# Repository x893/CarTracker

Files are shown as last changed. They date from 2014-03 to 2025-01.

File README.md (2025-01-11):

CarTracker
==========

CarTracker
STM32F10xCx, STM32F10xRx, STM32F205Rx, STM32F405Rx, STM32L1xxCx, STM32L1xxRx support.
Telit SL868 or SL869
Telit GL865 or GL868
CAN support,
MMA7455 accelerometer,
standard SIM or SIM On Chip
64 pins version can use battery, USB and RFM70 module (or other)

Shared PCB on OSH Park:

Cx version http://oshpark.com/shared_projects/hou07XOD

Rx version http://oshpark.com/shared_projects/wFTza6Pe

Cx version support direct connection GPS to GSM via wires (or change layout) so you can use buildin Python to implement tracker functions without STM32 MCU.

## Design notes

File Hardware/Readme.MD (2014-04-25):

Eagle Cadsoft
Case http://www.gainta.com/en/g431.html
See info for R9 value and R13

Shared PCB on OSH Park:

Cx version http://oshpark.com/shared_projects/hou07XOD
Rx version http://oshpark.com/shared_projects/wFTza6Pe

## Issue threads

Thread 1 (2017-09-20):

Online Diagnostic and GPS

aytekno, 2017-09-20:
Hello,
We want to use your product for online diagnostic and tracking. We do not want the processes online, just want to record the data on a SD card . We opened the pcb files and we could not see micro sd card slot. In your previous design there was. What do you prefer? Have you ever try this card for CanBus?
Thank you in advance.

x893, 2017-09-20:
Hello, SD card not need for my application. But you can add SD card to board or redesign for your box. My board (both variants) contains CAN adapter but also you can add modern CAN bus variants. So you can change as you need. You can contact with me via skype - see in top left corner on my site.

toxatt, 2019-05-10:
Hello. Have you realization collecting data to flash memory when have no GSM signal?

x893, 2019-05-24:
Yes, many years ago. As ring buffer but for microtracker (MX25 flash chip). See on site my site for device. Algorithm very simple - nothing interesting.

Closed 2025-01-11.

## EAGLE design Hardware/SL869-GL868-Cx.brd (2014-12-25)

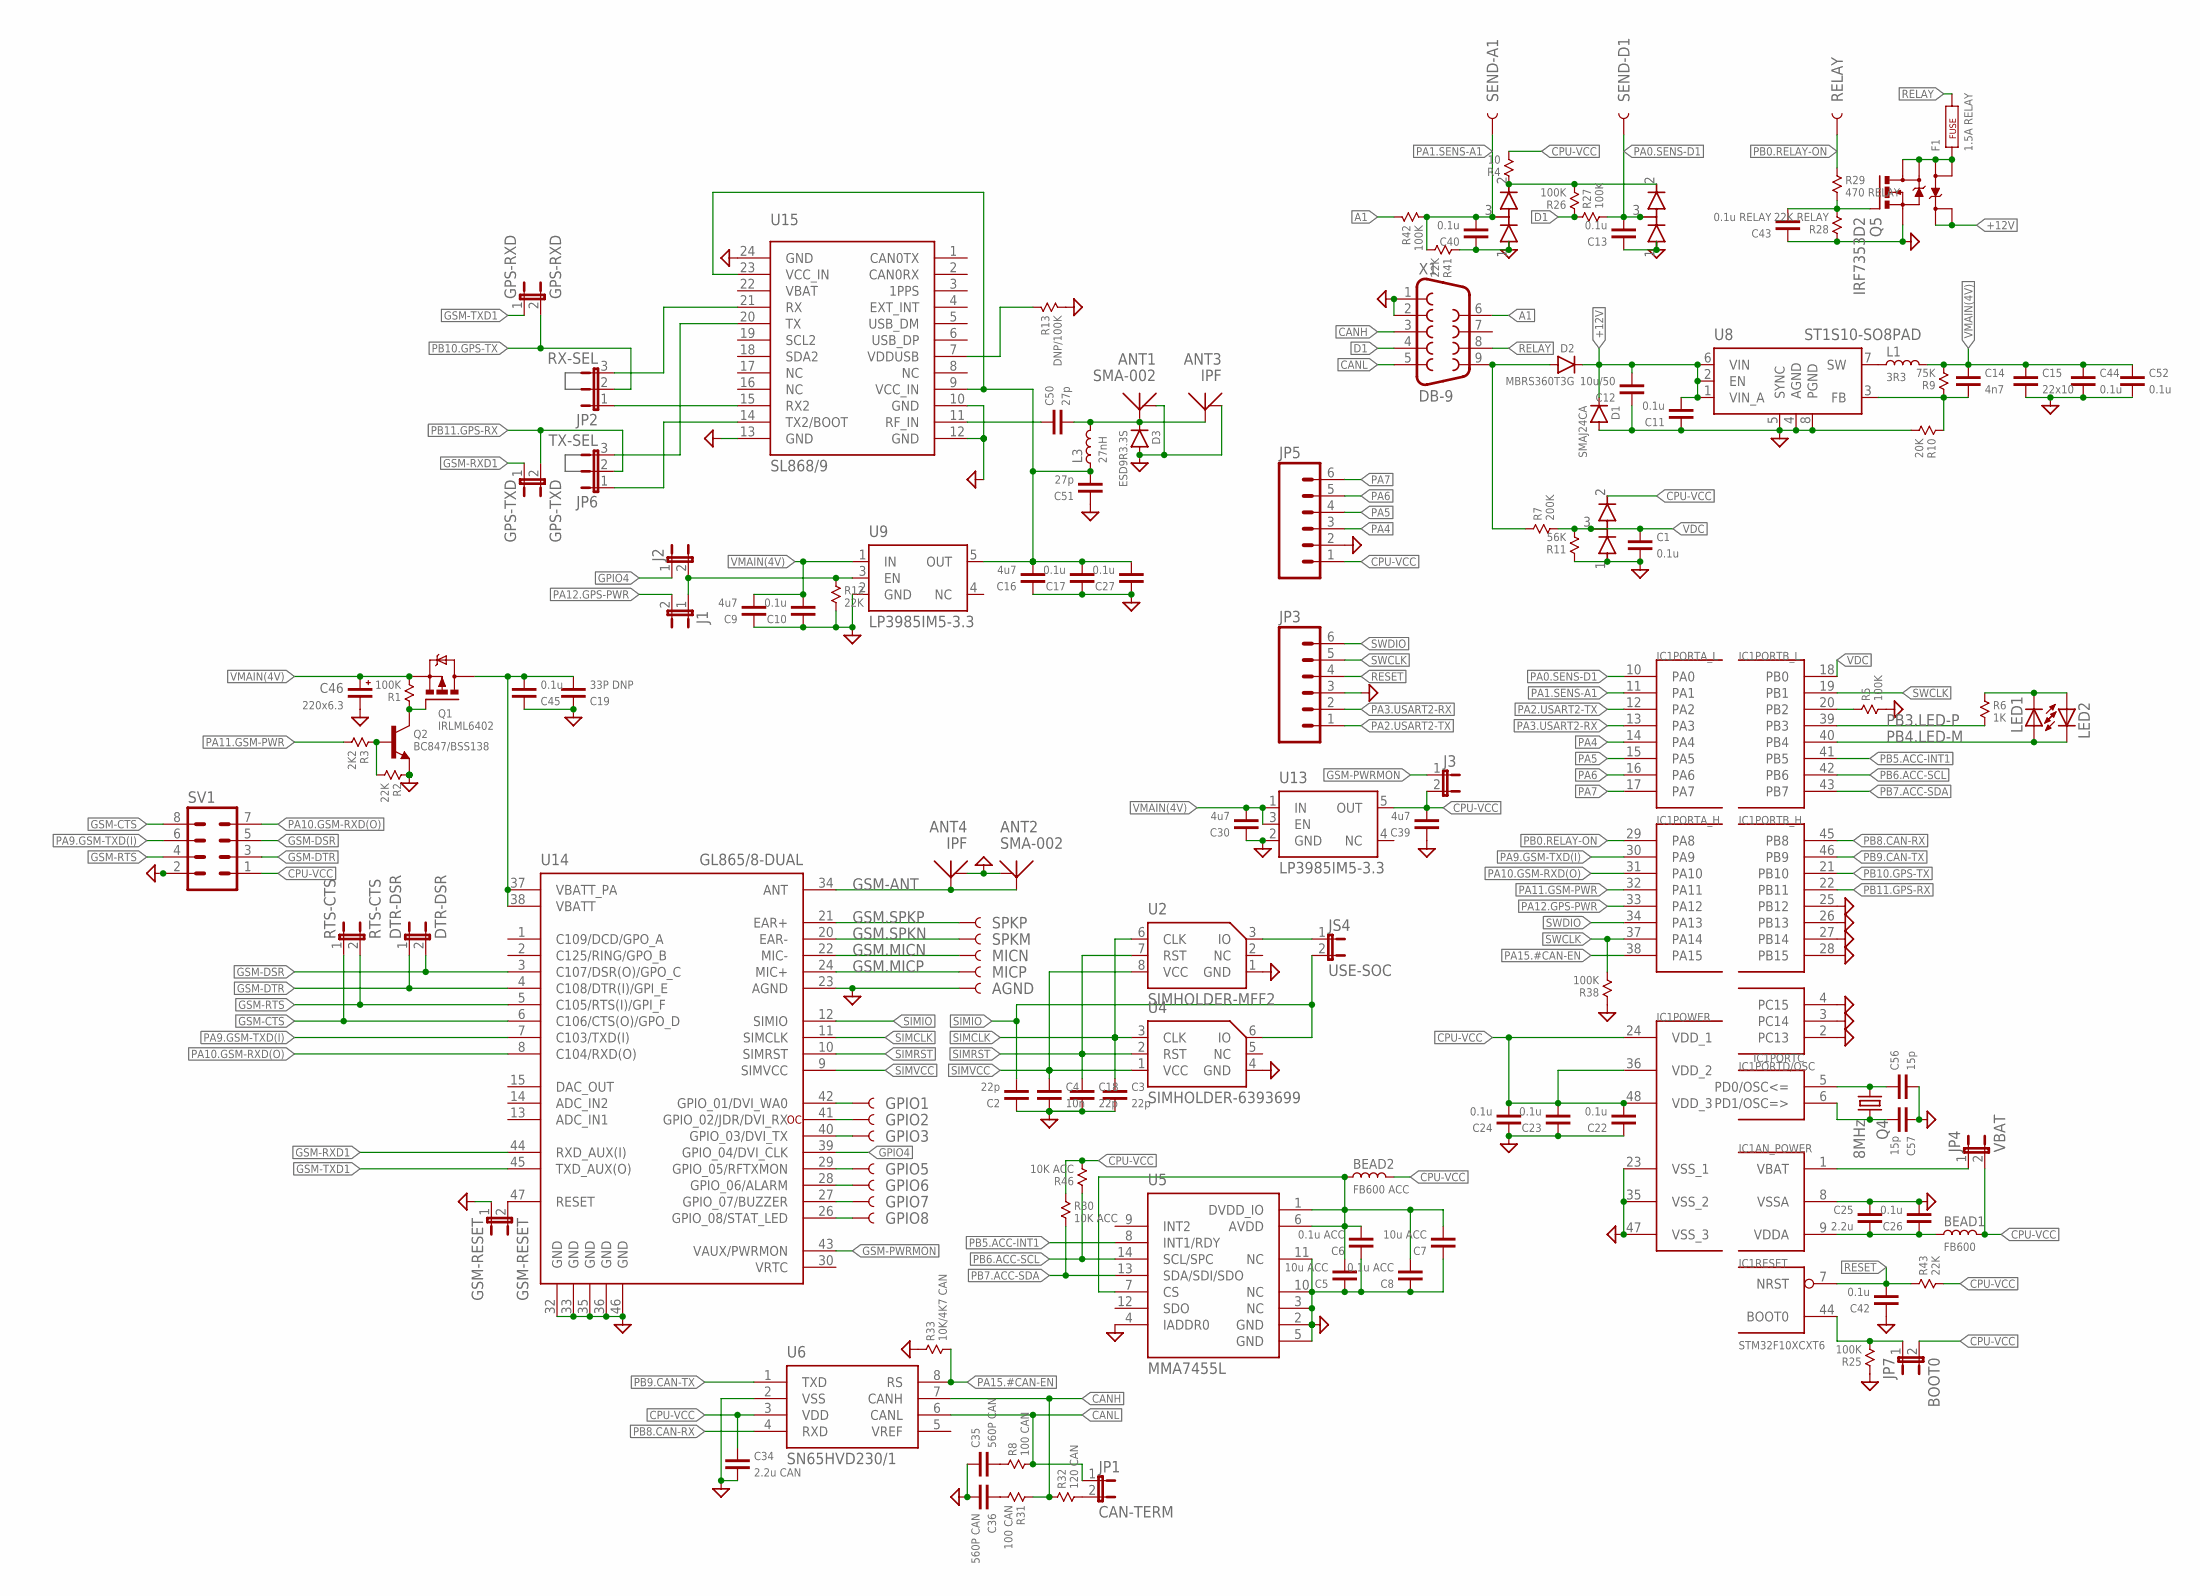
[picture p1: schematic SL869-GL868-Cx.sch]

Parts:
AGND: TEST-POINT1; PAD.1X1
ANT1, ANT2: SMA-002
ANT3, ANT4: IPF; MM9329
BEAD1: FB600; 0603
BEAD2: FB600 ACC; 0603
C1, C10, C11, C13, C17, C22, C23, C24, C26, C27, C40, C42, C44, C45, C52: 0.1u; 0603
C2, C3, C18: 22p; 0603
C4: 10n; 0603
C5, C7: 10u ACC; 0603
C6, C8: 0.1u ACC; 0603
C9, C16, C30, C39: 4u7; 0603
C12: 10u/50; 1206
C14: 4n7; 0603
C15: 22x10; 1206
C19: 33P DNP; 0603
C25: 2.2u; 0603
C34: 2.2u CAN; 0603
C35, C36: 560P CAN; 0603
C43: 0.1u RELAY; 0603
C46: 220x6.3; CT7343
C50, C51: 27p; 0603
C56, C57: 15p; 0603
D1: SMAJ24CA; SMA
D2: MBRS360T3G; SMC
D3: ESD9R3.3S; SOD-923
D4, D5, D14: BAV99; SOT-23
DTR-DSR: DTR-DSR; SJ_2S-NO
F1: 1.5A RELAY; 1812
GPIO1, GPIO2, GPIO3, GPIO5, GPIO6, GPIO7, GPIO8: TEST-POINT1; PAD.1X1
GPS-RXD: GPS-RXD; SJ_2S-NO
GPS-TXD: GPS-TXD; SJ_2S-NO
GSM-RESET: GSM-RESET; SJ_2S-NO
IC1: STM32F10XCXT6; TQFP48
J1, J2, J3: JUMPER-2SMD-NO; SJ_2S-NO
JP1: CAN-TERM; SJ_2S-NO
JP2: RX-SEL; SJ_3
JP3, JP5: M06SIP; 1X06
JP4: VBAT; SJ_2S-NO
JP6: TX-SEL; SJ_3
JP7: BOOT0; SJ_2S-NO
JS4: USE-SOC; SJ_2S-NO
L1: 3R3; CDRH6D38NP
L3: 27nH; 0603
LED1, LED2: LED3MM
MICN: TEST-POINT1; PAD.1X1
MICP: TEST-POINT1; PAD.1X1
Q1: IRLML6402; SOT-23
Q2: BC847/BSS138; SOT-23
Q4: 8MHz; HC49U-V
Q5: IRF7353D2; SO08
R1, R5, R25, R26, R27, R38, R42: 100K; 0603
R2, R12, R41, R43: 22K; 0603
R3: 2K2; 0603
R4: 10; 0603
R6: 1K; 0603
R7: 200K; 0603
R8, R31: 100 CAN; 0603
R9: 75K; 0603
R10: 20K; 0603
R11: 56K; 0603
R13: DNP/100K; 0603
R28: 22K RELAY; 0603
R29: 470 RELAY; 0603
R30, R46: 10K ACC; 0603
R32: 120 CAN; 0603
R33: 10K/4K7 CAN; 0603
RELAY: TEST-POINT1; PAD.1X1
RTS-CTS: RTS-CTS; SJ_2S-NO
SEND-A1: TEST-POINT1; PAD.1X1
SEND-D1: TEST-POINT1; PAD.1X1
SPKM: TEST-POINT1; PAD.1X1
SPKP: TEST-POINT1; PAD.1X1
SV1: MA04-2
U2: SIMHOLDER-MFF2; MFF2
U4: SIMHOLDER-6393699; 6393699-1
U5: MMA7455L; LGA14
U6: SN65HVD230/1; SO08
U8: ST1S10-SO8PAD; SO08-EPAD
U9, U13: LP3985IM5-3.3; SOT23-5
U14: GL865/8-DUAL
U15: SL868/9
X1: DB-9; DB9

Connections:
+12-IN: D2.P$2 (A), R7.1, X1.9
+12V: C11.1, C12.1, D1.P$1 (C), D2.P$1 (C), Q5.7 (K), Q5.8 (K), U8.1 (VIN_A), U8.2 (EN), U8.6 (VIN)
A1: R42.1, X1.6
ACC-VCC: BEAD2.1, C5.1, C6.1, C7.1, C8.1, U5.1 (DVDD_IO), U5.6 (AVDD), U5.7 (CS)
CANH: R31.1, R32.1, U6.7 (CANH), X1.3
CANL: JP1.1, R8.2, U6.6 (CANL), X1.5
CPU-VBAT: IC1.1 (VBAT), JP4.1
CPU-VCC: BEAD1.2, BEAD2.2, C22.1, C23.1, C24.1, C34.2, C39.1, D5.2 (+), IC1.24 (VDD_1), IC1.36 (VDD_2), IC1.48 (VDD_3), J3.2, JP4.2, JP5.1, JP7.2, R4.2, R30.1, R43.2, R46.2, SV1.1, U6.3 (VDD), U13.5 (OUT)
D1: R26.1, R27.1, X1.4
GND: AGND.P$1, ANT1.GND@1 (GND), ANT2.GND@1 (GND), ANT3.2 (GND), ANT4.2 (GND), C1.1, C2.2, C3.1, C4.1, C5.2, C6.2, C7.2, C8.2, C9.2, C10.2, C11.2, C12.2, C13.2, C15.1, C16.2, C17.2, C18.1, C19.2, C22.2, C23.2, C24.2, C25.2, C26.1, C27.2, C30.2, C34.1, C35.2, C36.1, C39.2, C40.2, C42.2, C43.2, C44.1, C45.2, C46.-, C51.2, C52.1, C56.1, C57.2, D1.P$2 (A), D3.2 (A), D4.1 (-), D5.1 (-), D14.1 (-), GSM-RESET.1, IC1.2 (PC13), IC1.3 (PC14), IC1.4 (PC15), IC1.8 (VSSA), IC1.23 (VSS_1), IC1.25 (PB12), IC1.26 (PB13), IC1.27 (PB14), IC1.28 (PB15), IC1.35 (VSS_2), IC1.47 (VSS_3), JP3.3, JP5.2, Q2.2 (E), Q5.3 (S), R2.1, R5.2, R10.2, R11.1, R12.2, R13.2, R25.1, R28.1, R33.1, R38.1, R41.1, SV1.2, U2.1 (GND), U4.4 (GND), U5.2 (GND), U5.3 (NC), U5.4 (IADDR0), U5.5 (GND), U5.10 (NC), U5.11 (NC), U6.2 (VSS), U8.4 (AGND), U8.5 (SYNC), U8.8 (PGND), U9.2 (GND), U13.2 (GND), U14.23 (AGND), U14.32 (GND), U14.33 (GND), U14.35 (GND), U14.36 (GND), U14.46 (GND), U15.10 (GND), U15.12 (GND), U15.13 (GND), U15.24 (GND), X1.1, X1.2
GPIO1: GPIO1.P$1, U14.42 (GPIO_01/DVI_WA0)
GPIO2: GPIO2.P$1, U14.41 (GPIO_02/JDR/DVI_RX)
GPIO3: GPIO3.P$1, U14.40 (GPIO_03/DVI_TX)
GPIO4: J2.1, U14.39 (GPIO_04/DVI_CLK)
GPIO5: GPIO5.P$1, U14.29 (GPIO_05/RFTXMON)
GPIO6: GPIO6.P$1, U14.28 (GPIO_06/ALARM)
GPIO7: GPIO7.P$1, U14.27 (GPIO_07/BUZZER)
GPIO8: GPIO8.P$1, U14.26 (GPIO_08/STAT_LED)
GPS-PWR: J1.1, J2.2, R12.1, U9.3 (EN)
GPS-RX0: JP2.1, U15.15 (RX2)
GPS-RX1: JP2.3, U15.21 (RX)
GPS-TX0: JP6.1, U15.14 (TX2/BOOT)
GPS-TX1: JP6.3, U15.20 (TX)
GPS-VCC: C16.1, C17.1, C27.1, C51.1, L3.1, U9.5 (OUT), U15.9 (VCC_IN), U15.23 (VCC_IN)
GSM-ANT: ANT2.A (ANT), ANT4.1 (ANT), U14.34 (ANT)
GSM-CTS: RTS-CTS.1, SV1.8, U14.6 (C106/CTS(O)/GPO_D)
GSM-DSR: DTR-DSR.2, SV1.5, U14.3 (C107/DSR(O)/GPO_C)
GSM-DTR: DTR-DSR.1, SV1.3, U14.4 (C108/DTR(I)/GPI_E)
GSM-PWRMON: J3.1, U14.43 (VAUX/PWRMON)
GSM-RESET: GSM-RESET.2, U14.47 (RESET)
GSM-RTS: RTS-CTS.2, SV1.4, U14.5 (C105/RTS(I)/GPI_F)
GSM-RXD1: GPS-TXD.1, U14.44 (RXD_AUX(I))
GSM-TXD1: GPS-RXD.1, U14.45 (TXD_AUX(O))
GSM-VCC: C19.1, C45.1, Q1.3 (D), U14.37 (VBATT_PA), U14.38 (VBATT)
GSM.MICN: MICN.P$1, U14.22 (MIC-)
GSM.MICP: MICP.P$1, U14.24 (MIC+)
GSM.SPKN: SPKM.P$1, U14.20 (EAR-)
GSM.SPKP: SPKP.P$1, U14.21 (EAR+)
unnamed: JP1.2, R32.2
unnamed: IC1.20 (PB2), R5.1
unnamed: F1.1, Q5.1 (A), Q5.2 (A), Q5.5 (D), Q5.6 (D)
unnamed: Q1.1 (G), Q2.3 (C), R1.1
unnamed: JS4.1, U2.3 (IO)
unnamed: C50.2, U15.11 (RF_IN)
unnamed: Q2.1 (B), R2.2, R3.1
unnamed: L1.P$1 (1), U8.7 (SW)
unnamed: C35.1, R8.1
unnamed: C36.2, R31.2
unnamed: R13.1, U15.7 (VDDUSB)
unnamed: LED1.K (C), LED2.A, R6.1
unnamed: C56.2, IC1.5 (PD0/OSC<=), Q4.1
unnamed: IC1.44 (BOOT0), JP7.1, R25.2
unnamed: C14.1, R9.1, R10.1, U8.3 (FB)
unnamed: C57.1, IC1.6 (PD1/OSC=>), Q4.2
unnamed: ANT1.A (ANT), ANT3.1 (ANT), C50.1, D3.1 (C), L3.2
unnamed: C43.1, Q5.4 (G), R28.2, R29.2
PA0.SENS-D1: C13.1, D4.3 (S), IC1.10 (PA0), R27.2, SEND-D1.P$1
PA1.SENS-A1: C40.1, D14.3 (S), IC1.11 (PA1), R41.2, R42.2, SEND-A1.P$1
PA2.USART2-TX: IC1.12 (PA2), JP3.1
PA3.USART2-RX: IC1.13 (PA3), JP3.2
PA4: IC1.14 (PA4), JP5.3
PA5: IC1.15 (PA5), JP5.4
PA6: IC1.16 (PA6), JP5.5
PA7: IC1.17 (PA7), JP5.6
PA9.GSM-TXD(I): IC1.30 (PA9), SV1.6, U14.7 (C103/TXD(I))
PA10.GSM-RXD(O): IC1.31 (PA10), SV1.7, U14.8 (C104/RXD(O))
PA11.GSM-PWR: IC1.32 (PA11), R3.2
PA12.GPS-PWR: IC1.33 (PA12), J1.2
PA15.#CAN-EN: IC1.38 (PA15), R33.2, U6.8 (RS)
PB0.RELAY-ON: IC1.29 (PA8), R29.1, RELAY.P$1
PB3.LED-P: IC1.39 (PB3), R6.2
PB4.LED-M: IC1.40 (PB4), LED1.A, LED2.K (C)
PB5.ACC-INT1: IC1.41 (PB5), U5.8 (INT1/RDY)
PB6.ACC-SCL: IC1.42 (PB6), R46.1, U5.14 (SCL/SPC)
PB7.ACC-SDA: IC1.43 (PB7), R30.2, U5.13 (SDA/SDI/SDO)
PB8.CAN-RX: IC1.45 (PB8), U6.4 (RXD)
PB9.CAN-TX: IC1.46 (PB9), U6.1 (TXD)
PB10.GPS-TX: GPS-RXD.2, IC1.21 (PB10), JP2.2
PB11.GPS-RX: GPS-TXD.2, IC1.22 (PB11), JP6.2
RELAY: F1.2, X1.8
RESET: C42.1, IC1.7 (NRST), JP3.4, R43.1
SENS-VCC: D4.2 (+), D14.2 (+), R4.1, R26.2
SIMCLK: C3.2, U2.6 (CLK), U4.3 (CLK), U14.11 (SIMCLK)
SIMIO: C2.1, JS4.2, U4.6 (IO), U14.12 (SIMIO)
SIMRST: C18.2, U2.7 (RST), U4.2 (RST), U14.10 (SIMRST)
SIMVCC: C4.2, U2.8 (VCC), U4.1 (VCC), U14.9 (SIMVCC)
SWCLK: IC1.19 (PB1), IC1.37 (PA14), JP3.5, R38.2
SWDIO: IC1.34 (PA13), JP3.6
VDC: C1.2, D5.3 (S), IC1.18 (PB0), R7.2, R11.2
VDDA: BEAD1.1, C25.1, C26.2, IC1.9 (VDDA)
VMAIN(4V): C9.1, C10.1, C14.2, C15.2, C30.1, C44.2, C46.+, C52.2, L1.P$2 (2), Q1.2 (S), R1.2, R9.2, U9.1 (IN), U13.1 (IN), U13.3 (EN)

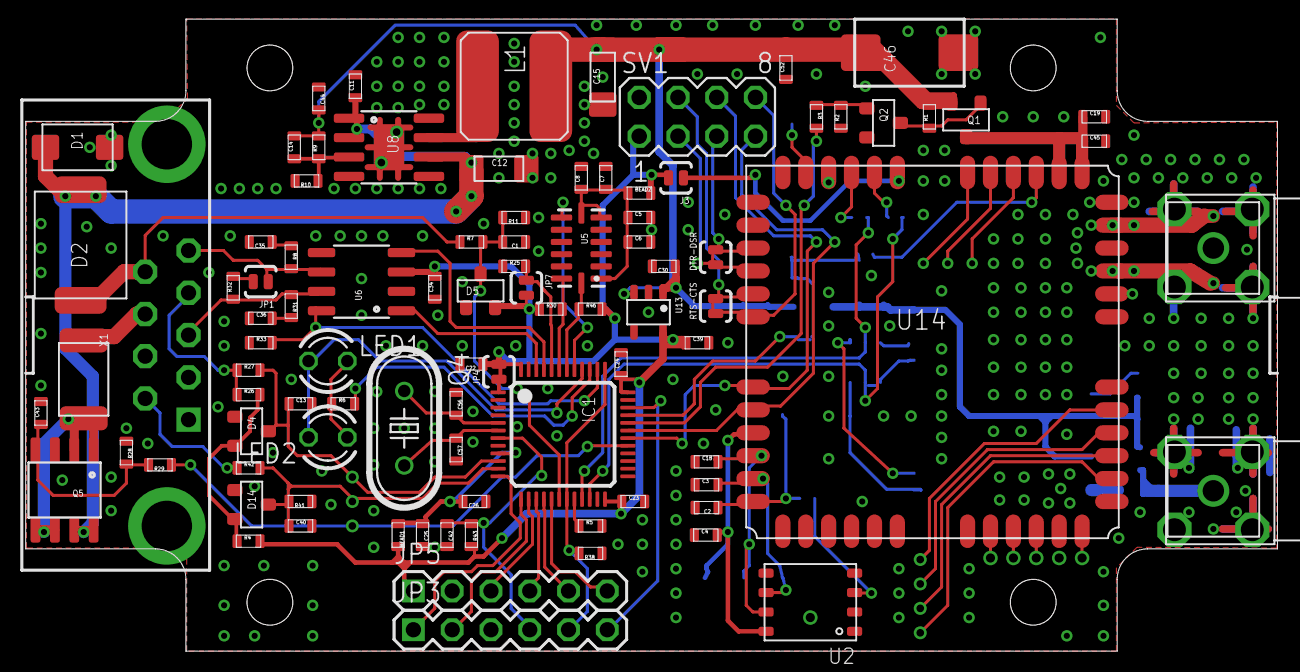
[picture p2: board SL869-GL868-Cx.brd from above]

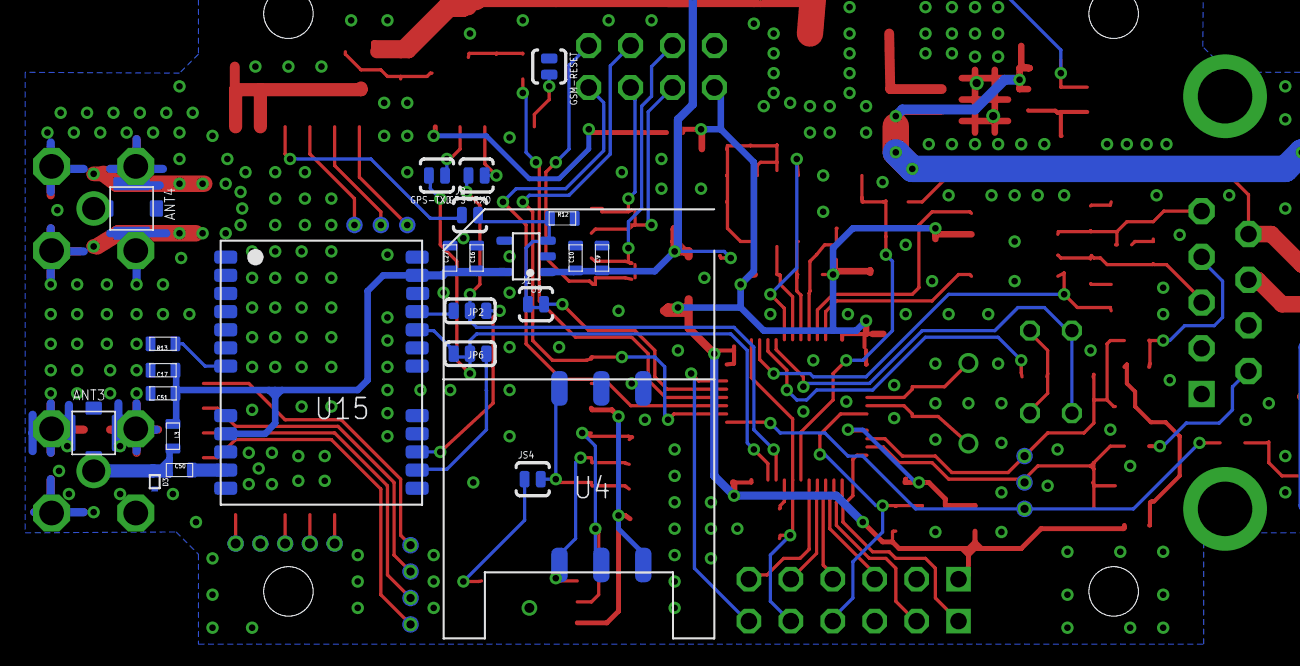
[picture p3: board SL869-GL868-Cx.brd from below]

Board: 2 copper layers, 133 parts (39 on the bottom side), 91 nets.

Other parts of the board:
U$1: G403

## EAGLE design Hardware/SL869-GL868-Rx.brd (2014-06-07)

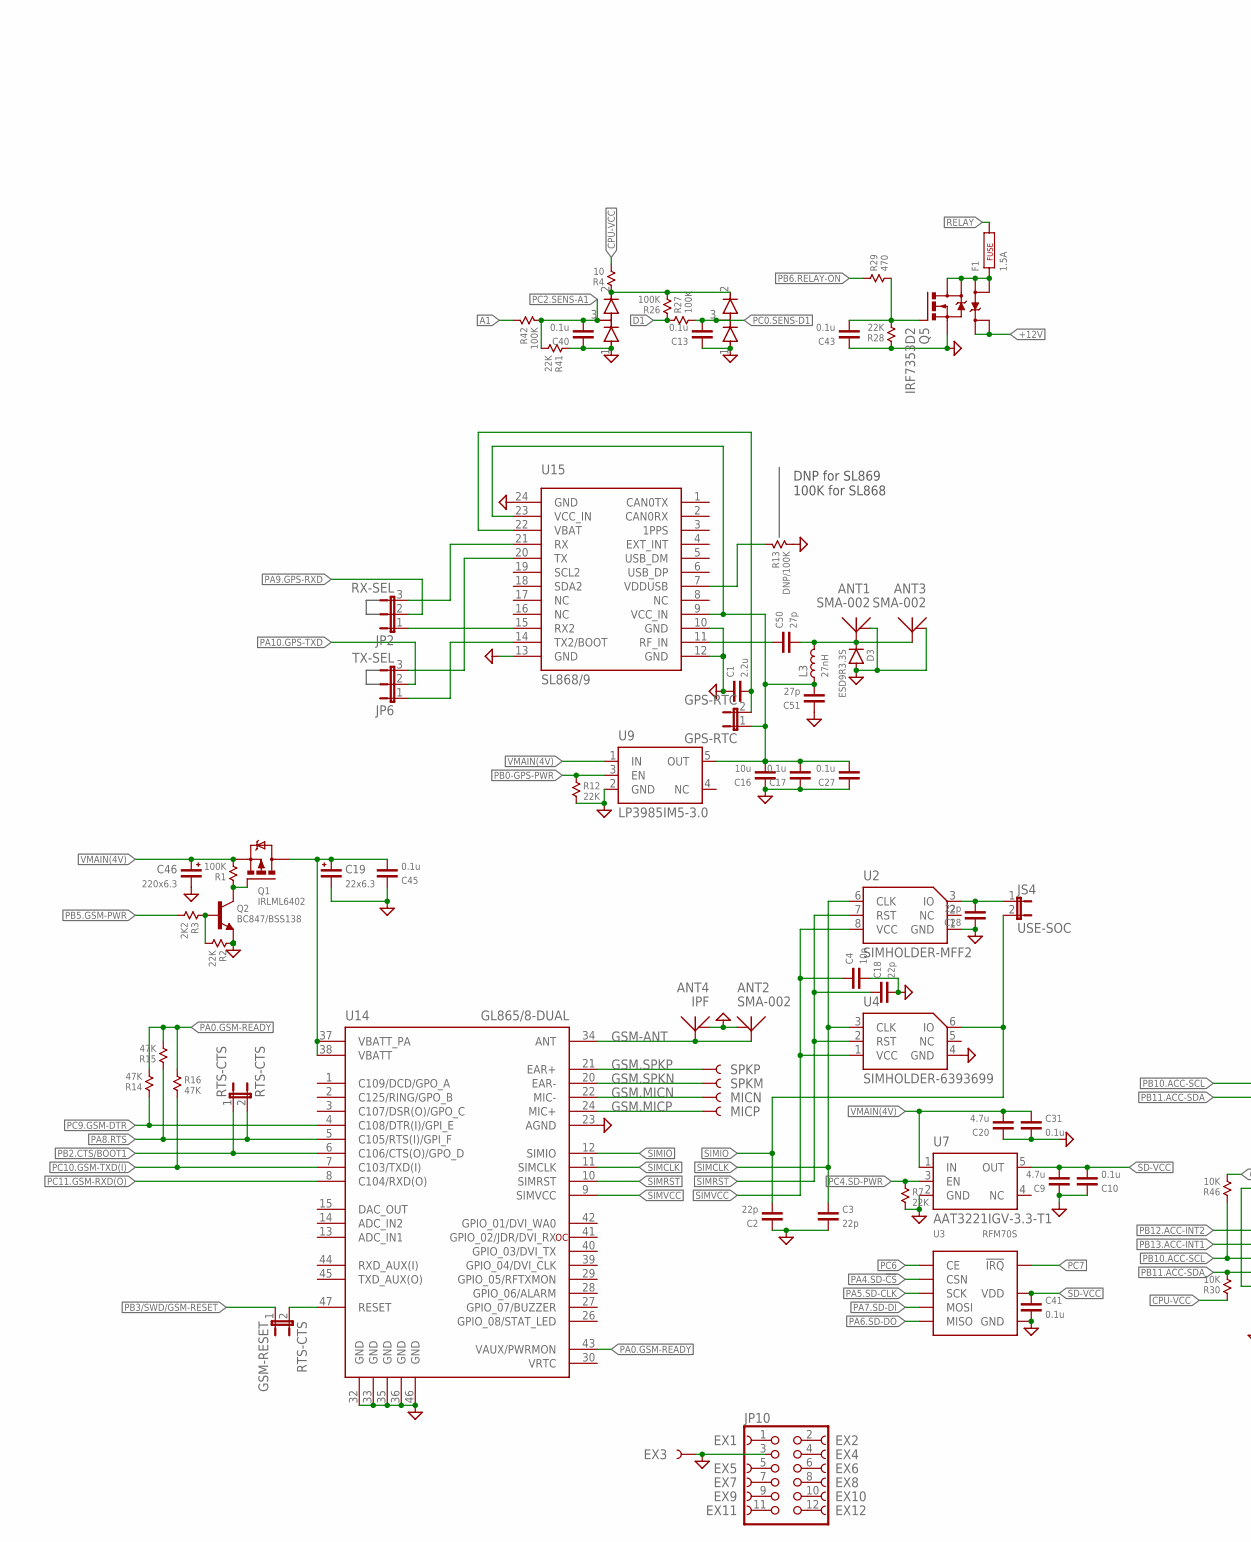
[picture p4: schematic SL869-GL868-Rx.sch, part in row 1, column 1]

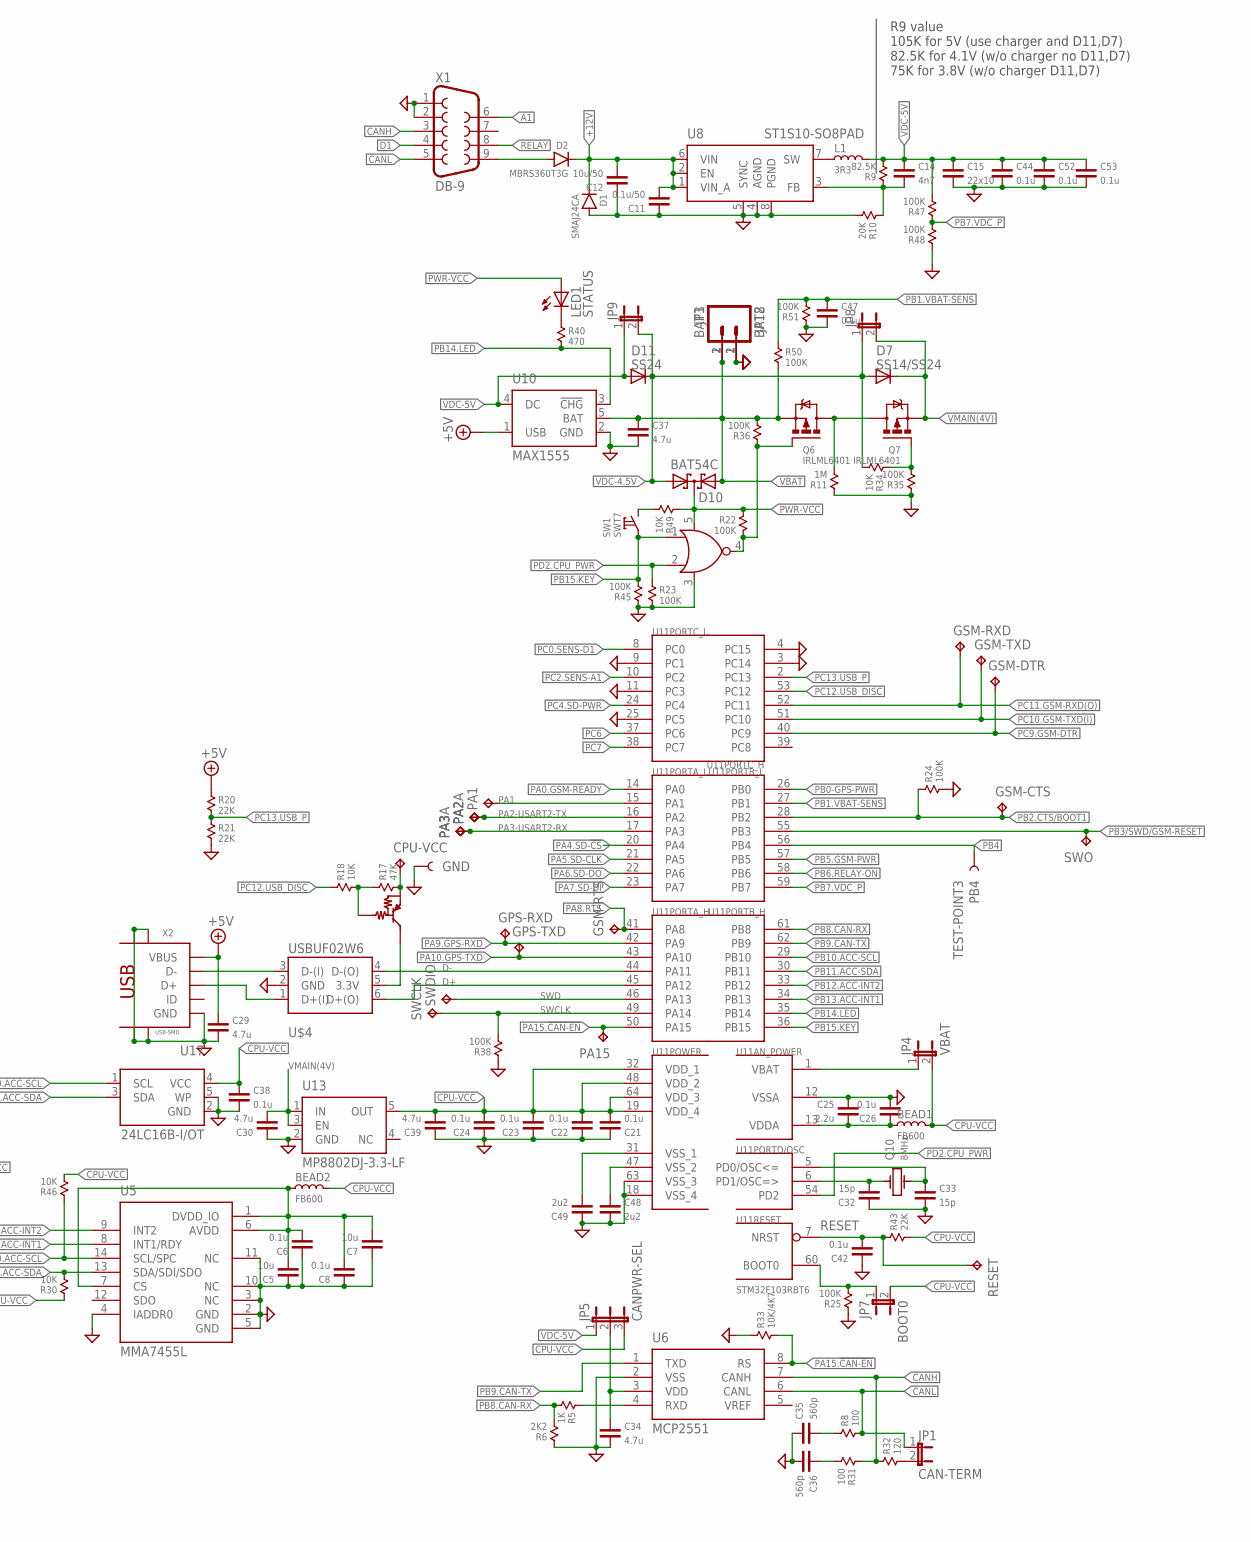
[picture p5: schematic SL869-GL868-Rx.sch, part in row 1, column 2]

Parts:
ANT1, ANT2: SMA-002
ANT3: SMA-002; MM9329
ANT4: IPF; MM9329
BEAD1, BEAD2: FB600; 0603
C1, C25: 2.2u; 0603
C2, C3, C18, C28: 22p; 0603
C4: 10n; 0603
C5, C7, C16: 10u; 0603
C6, C8, C10, C13, C17, C21, C22, C23, C24, C26, C27, C31, C38, C40, C41, C42, C43, C44, C45, C47, C52, C53: 0.1u; 0603
C9, C20, C29, C30, C34, C37, C39: 4.7u; 0603
C11: 0.1u/50; 0603
C12: 10u/50; 1206
C14: 4n7; 0603
C15: 22x10; 1206
C19: 22x6.3; CT3528
C32, C33: 15p; 0603
C35, C36: 560p; 0603
C46: 220x6.3; CT7343
C48, C49: 2u2; 0603
C50, C51: 27p; 0603
CPU-VCC: TPTP09R; TP09R
D1: SMAJ24CA; SMA
D2: MBRS360T3G; SMC
D3: ESD9R3.3S; SOD-923
D4, D14: BAV99; SOT-23
D7: SS14/SS24; SMA-DIODE
D10: BAT54C; SOT23
D11: SS24; SMA-DIODE
EX1, EX2, EX3, EX4, EX5, EX6, EX7, EX8, EX9, EX10, EX11, EX12: TEST-POINT1; PAD.1X1
F1: 1.5A; 1812
GND: TEST-POINT3; PAD.03X.03
GPS-RTC: GPS-RTC; SJ_2S-NO
GPS-RXD: TPTP07R; TP07R
GPS-TXD: TPTP07R; TP07R
GSM-CTS: TPTP07R; TP07R
GSM-DTR: TPTP07R; TP07R
GSM-RESET: RTS-CTS; SJ_2S-NO
GSM-RTS: TPTP07R; TP07R
GSM-RXD: TPTP07R; TP07R
GSM-TXD: TPTP07R; TP07R
JP1: CAN-TERM; SJ_2S-NO
JP2: RX-SEL; SJ_3
JP3: BAT2; S2B-PH
JP4: VBAT; SJ_2S-NO
JP5: CANPWR-SEL; SJ_3
JP6: TX-SEL; SJ_3
JP7: BOOT0; SJ_2S-NO
JP8, JP9: JUMPER-2SMD-NO; SJ_2S-NO
JP10: PINHD-2X6; 2X06
JP18: BAT1; CI1102M1H
JS4: USE-SOC; SJ_2S-NO
L1: 3R3; CDRH6D38NP
L3: 27nH; 0603
LED1: STATUS; LED3MM
MICN: TEST-POINT1; PAD.1X1
MICP: TEST-POINT1; PAD.1X1
PA1, PA2, PA3: TPTP08R; TP08R
PA2A, PA3A, PA15: TPTP07R; TP07R
PB4: TEST-POINT3; PAD.03X.03
Q1: IRLML6402; SOT-23
Q2: BC847/BSS138; SOT-23
Q5: IRF7353D2; SO08
Q6, Q7: IRLML6401; SOT-23
Q10: 8MHz; KX-9A
R1, R22, R23, R24, R25, R26, R27, R35, R36, R38, R42, R45, R47, R48, R50, R51: 100K; 0603
R2, R7, R12, R20, R21, R28, R41, R43: 22K; 0603
R3, R6: 2K2; 0603
R4: 10; 0603
R5: 1K; 0603
R8, R31: 100; 0603
R9: 82.5K; 0603
R10: 20K; 0603
R11: 1M; 0603
R13: DNP/100K; 0603
R14, R15, R16, R17: 47K; 0603
R18, R30, R34, R46, R49: 10K; 0603
R29, R40: 470; 0603
R32: 120; 0603
R33: 10K/4K7; 0603
RESET: TPTP09R; TP09R
RTS-CTS: RTS-CTS; SJ_2S-NO
SPKM: TEST-POINT1; PAD.1X1
SPKP: TEST-POINT1; PAD.1X1
SW1: SWT7; SWT-7
SWCLK: TPTP09R; TP09R
SWDIO: TPTP09R; TP09R
SWO: TPTP07R; TP07R
U1: 74LVC1G02GV; SOT-753
U2: SIMHOLDER-MFF2; MFF2
U3: RFM70S
U4: SIMHOLDER-6393699; 6393699-1
U5: MMA7455L; LGA14
U6: MCP2551; SO08
U7: AAT3221IGV-3.3-T1; SOT23-5
U8: ST1S10-SO8PAD; SO08-EPAD
U9: LP3985IM5-3.0; SOT23-5
U10: MAX1555; SOT23-5
U11: STM32F103RBT6; TQFP64
U13: MP8802DJ-3.3-LF; SOT23-5
U14: GL865/8-DUAL
U15: SL868/9
U17: 24LC16B-I/OT; SOT23-5
U$3: PDTA114ET; SOT-23
U$4: USBUF02W6; SOT323-6
X1: DB-9; DB9
X2: USB-SMD; USB-MINIB

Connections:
+5V: C29.2, R20.1, U10.1 (USB), X2.VBUS
+12-IN: D2.P$2 (A), X1.9
+12V: C11.1, C12.1, D1.P$1 (C), D2.P$1 (C), Q5.7 (K), Q5.8 (K), U8.1 (VIN_A), U8.2 (EN), U8.6 (VIN)
A1: R42.1, X1.6
ACC-VCC: BEAD2.1, C5.1, C6.1, C7.1, C8.1, U5.1 (DVDD_IO), U5.6 (AVDD), U5.7 (CS)
CANH: R31.1, R32.1, U6.7 (CANH), X1.3
CANL: JP1.1, R8.2, U6.6 (CANL), X1.5
CPU-VBAT: JP4.1, U11.1 (VBAT)
CPU-VCC: BEAD1.2, BEAD2.2, C21.1, C22.1, C23.1, C24.1, C38.2, C39.1, CPU-VCC.TP, JP4.2, JP5.3, JP7.2, R4.2, R17.2, R30.1, R43.2, R46.2, U11.19 (VDD_4), U11.32 (VDD_1), U11.48 (VDD_2), U11.64 (VDD_3), U13.5 (OUT), U17.4 (VCC), U$3.2
D1: R26.1, R27.1, X1.4
D+: U11.45 (PA12), U$4.6 (D+(O))
D-: U11.44 (PA11), U$4.4 (D-(O))
GND: ANT1.GND@1 (GND), ANT2.GND@1 (GND), ANT3.2 (GND), ANT4.2 (GND), C1.2, C2.2, C3.1, C4.1, C5.2, C6.2, C7.2, C8.2, C9.2, C10.2, C11.2, C12.2, C13.2, C15.1, C16.2, C17.2, C18.1, C19.-, C20.2, C21.2, C22.2, C23.2, C24.2, C25.2, C26.1, C27.2, C28.2, C29.1, C30.2, C31.1, C32.2, C33.1, C34.1, C35.2, C36.1, C37.1, C38.1, C39.2, C40.2, C41.1, C42.2, C43.2, C44.1, C45.2, C46.-, C47.1, C48.1, C49.2, C51.2, C52.1, C53.1, D1.P$2 (A), D3.2 (A), D4.1 (-), D14.1 (-), EX3.P$1, GND.P$1, JP3.1, JP10.3, JP18.2, Q2.2 (E), Q5.3 (S), R2.1, R6.1, R7.2, R10.2, R11.1, R12.2, R13.2, R21.2, R23.2, R24.2, R25.1, R28.1, R33.1, R35.1, R38.1, R41.1, R45.1, R48.1, R51.1, U1.3 (GND), U2.1 (GND), U3.GND, U4.4 (GND), U5.2 (GND), U5.3 (NC), U5.4 (IADDR0), U5.5 (GND), U5.10 (NC), U5.11 (NC), U6.2 (VSS), U7.2 (GND), U8.4 (AGND), U8.5 (SYNC), U8.8 (PGND), U9.2 (GND), U10.2 (GND), U11.3 (PC14), U11.4 (PC15), U11.9 (PC1), U11.11 (PC3), U11.12 (VSSA), U11.18 (VSS_4), U11.25 (PC5), U11.63 (VSS_3), U13.2 (GND), U14.23 (AGND), U14.32 (GND), U14.33 (GND), U14.35 (GND), U14.36 (GND), U14.46 (GND), U15.10 (GND), U15.12 (GND), U15.13 (GND), U15.24 (GND), U17.2 (GND), U17.5 (WP), U$4.2 (GND), X1.1, X1.2, X2.GND, X2.GND@1 (GND), X2.GND@2 (GND), X2.GND@3 (GND), X2.GND@4 (GND)
GPS-RX0: JP2.1, U15.15 (RX2)
GPS-RX1: JP2.3, U15.21 (RX)
GPS-TX0: JP6.1, U15.14 (TX2/BOOT)
GPS-TX1: JP6.3, U15.20 (TX)
GPS-VCC: C16.1, C17.1, C27.1, C51.1, GPS-RTC.1, L3.1, U9.5 (OUT), U15.9 (VCC_IN), U15.23 (VCC_IN)
GSM-ANT: ANT2.A (ANT), ANT4.1 (ANT), U14.34 (ANT)
GSM-RESET: GSM-RESET.2, U14.47 (RESET)
GSM-VCC: C19.+, C45.1, Q1.3 (D), U14.37 (VBATT_PA), U14.38 (VBATT)
GSM.MICN: MICN.P$1, U14.22 (MIC-)
GSM.MICP: MICP.P$1, U14.24 (MIC+)
GSM.SPKN: SPKM.P$1, U14.20 (EAR-)
GSM.SPKP: SPKP.P$1, U14.21 (EAR+)
unnamed: JP1.2, R32.2
unnamed: U$3.3, U$4.5 (3.3V)
unnamed: C1.1, GPS-RTC.2, U15.22 (VBAT)
unnamed: Q7.1 (G), R34.1, R35.2
unnamed: F1.1, Q5.1 (A), Q5.2 (A), Q5.5 (D), Q5.6 (D)
unnamed: Q1.1 (G), Q2.3 (C), R1.1
unnamed: C49.1, U11.31 (VSS_1)
unnamed: C48.2, U11.47 (VSS_2)
unnamed: C28.1, JS4.1, U2.3 (IO)
unnamed: C50.2, U15.11 (RF_IN)
unnamed: Q2.1 (B), R2.2, R3.1
unnamed: L1.P$1 (1), U8.7 (SW)
unnamed: C35.1, R8.1
unnamed: C36.2, R31.2
unnamed: R13.1, U15.7 (VDDUSB)
unnamed: LED1.K (C), R40.1
unnamed: R5.1, U6.4 (RXD)
unnamed: C34.2, JP5.2, U6.3 (VDD)
unnamed: EX1.P$1, JP10.1
unnamed: EX2.P$1, JP10.2
unnamed: EX4.P$1, JP10.4
unnamed: C32.1, Q10.1, U11.6 (PD1/OSC=>)
unnamed: EX5.P$1, JP10.5
unnamed: JP7.1, R25.2, U11.60 (BOOT0)
unnamed: C14.1, R9.1, R10.1, U8.3 (FB)
unnamed: EX6.P$1, JP10.6
unnamed: EX7.P$1, JP10.7
unnamed: EX8.P$1, JP10.8
unnamed: EX9.P$1, JP10.9
unnamed: EX10.P$1, JP10.10
unnamed: ANT1.A (ANT), ANT3.1 (ANT), C50.1, D3.1 (C), L3.2
unnamed: EX11.P$1, JP10.11
unnamed: EX12.P$1, JP10.12
unnamed: R49.2, SW1.2
unnamed: Q6.3 (D), Q7.3 (D), R11.2
unnamed: C43.1, Q5.4 (G), R28.2, R29.2
unnamed: U$4.3 (D-(I)), X2.D-
unnamed: U$4.1 (D+(I)), X2.D+
unnamed: C33.2, Q10.3 (2), U11.5 (PD0/OSC<=)
unnamed: R17.1, R18.2, U$3.1
PA0.GSM-READY: R14.2, R15.2, R16.1, U11.14 (PA0), U14.43 (VAUX/PWRMON)
PA1: PA1.TP, U11.15 (PA1)
PA2-USART2-TX: PA2.TP, PA2A.TP, U11.16 (PA2)
PA3-USART2-RX: PA3.TP, PA3A.TP, U11.17 (PA3)
PA4.SD-!CS: U3.CSN, U11.20 (PA4)
PA5.SD-CLK: U3.SCK, U11.21 (PA5)
PA6.SD-DO: U3.MISO, U11.22 (PA6)
PA7.SD-DI: U3.MOSI, U11.23 (PA7)
PA8.RTS: GSM-RTS.TP, R15.1, RTS-CTS.2, U11.41 (PA8), U14.5 (C105/RTS(I)/GPI_F)
PA9.GPS-RXD: GPS-RXD.TP, JP2.2, U11.42 (PA9)
PA10.GPS-TXD: GPS-TXD.TP, JP6.2, U11.43 (PA10)
PA15.!CAN-EN: PA15.TP, R33.2, U6.8 (RS), U11.50 (PA15)
PB0-GPS-PWR: R12.1, U9.3 (EN), U11.26 (PB0)
PB1.VBAT-SENS: C47.2, R50.1, R51.2, U11.27 (PB1)
PB2.CTS/BOOT1: GSM-CTS.TP, R24.1, RTS-CTS.1, U11.28 (PB2), U14.6 (C106/CTS(O)/GPO_D)
PB3/SWD/GSM-RESET: GSM-RESET.1, SWO.TP, U11.55 (PB3)
PB4: PB4.P$1, U11.56 (PB4)
PB5.GSM-PWR: R3.2, U11.57 (PB5)
PB6.RELAY-ON: R29.1, U11.58 (PB6)
PB7.VDC_P: R47.1, R48.2, U11.59 (PB7)
PB8.CAN-RX: R5.2, R6.2, U11.61 (PB8)
PB9.CAN-TX: U6.1 (TXD), U11.62 (PB9)
PB10.ACC-SCL: R46.1, U5.14 (SCL/SPC), U11.29 (PB10), U17.1 (SCL)
PB11.ACC-SDA: R30.2, U5.13 (SDA/SDI/SDO), U11.30 (PB11), U17.3 (SDA)
PB12.ACC-INT2: U5.9 (INT2), U11.33 (PB12)
PB13.ACC-INT1: U5.8 (INT1/RDY), U11.34 (PB13)
PB14.LED: R40.2, U10.3 (!CHG), U11.35 (PB14)
PB15.KEY: R45.2, SW1.1, U1.1 (A), U11.36 (PB15)
PC0.SENS-D1: C13.1, D4.3 (S), R27.2, U11.8 (PC0)
PC2.SENS-A1: C40.1, D14.3 (S), R41.2, R42.2, U11.10 (PC2)
PC4.SD-PWR: R7.1, U7.3 (EN), U11.24 (PC4)
PC6: U3.CE, U11.37 (PC6)
PC7: U3.IRQ (!IRQ), U11.38 (PC7)
PC9.GSM-DTR: GSM-DTR.TP, R14.1, U11.40 (PC9), U14.4 (C108/DTR(I)/GPI_E)
PC10.GSM-TXD(I): GSM-TXD.TP, R16.2, U11.51 (PC10), U14.7 (C103/TXD(I))
PC11.GSM-RXD(O): GSM-RXD.TP, U11.52 (PC11), U14.8 (C104/RXD(O))
PC12.USB_DISC: R18.1, U11.53 (PC12)
PC13.USB_P: R20.2, R21.1, U11.2 (PC13)
PD2.CPU_PWR: R23.1, U1.2 (B), U11.54 (PD2)
PWR-VCC: D10.3 (CC), LED1.A, R22.1, R49.1, U1.5 (VCC)
RELAY: F1.2, X1.8
RESET: C42.1, R43.1, RESET.TP, U11.7 (NRST)
SD-VCC: C9.1, C10.1, C41.2, U3.VDD, U7.5 (OUT)
SENS-VCC: D4.2 (+), D14.2 (+), R4.1, R26.2
SIMCLK: C3.2, U2.6 (CLK), U4.3 (CLK), U14.11 (SIMCLK)
SIMIO: C2.1, JS4.2, U4.6 (IO), U14.12 (SIMIO)
SIMRST: C18.2, U2.7 (RST), U4.2 (RST), U14.10 (SIMRST)
SIMVCC: C4.2, U2.8 (VCC), U4.1 (VCC), U14.9 (SIMVCC)
SWCLK: R38.2, SWCLK.TP, U11.49 (PA14)
SWD: SWDIO.TP, U11.46 (PA13)
VBAT: C37.2, D10.2 (A2), JP3.2, JP18.1, Q6.2 (S), R36.2, R50.2, U10.5 (BAT)
VDC-4.5V: D7.A, D10.1 (A1), D11.C, JP8.1, JP9.2, R34.2
VDC-5V: C14.2, C15.2, C44.2, C52.2, C53.2, D11.A, JP5.1, JP9.1, L1.P$2 (2), R9.2, R47.2, U10.4 (DC)
VDDA: BEAD1.1, C25.1, C26.2, U11.13 (VDDA)
VE: Q6.1 (G), R22.2, R36.1, U1.4 (Y)
VMAIN(4V): C20.1, C30.1, C31.2, C46.+, D7.C, JP8.2, Q1.2 (S), Q7.2 (S), R1.2, U7.1 (IN), U9.1 (IN), U13.1 (IN), U13.3 (EN)

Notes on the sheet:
R9 value 105K for 5V (use charger and D11,D7) 82.5K for 4.1V (w/o charger no D11,D7) 75K for 3.8V (w/o charger D11,D7)
DNP for SL869 100K for SL868

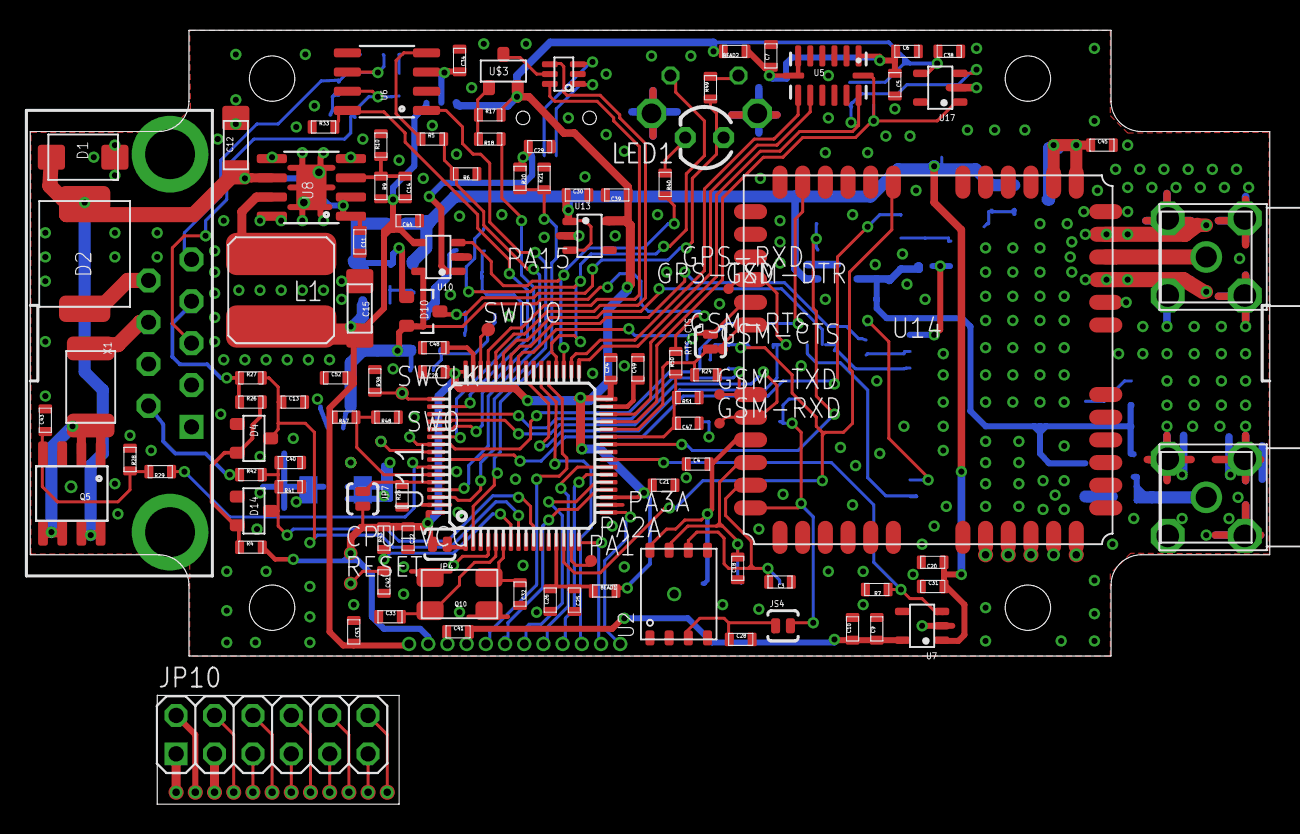
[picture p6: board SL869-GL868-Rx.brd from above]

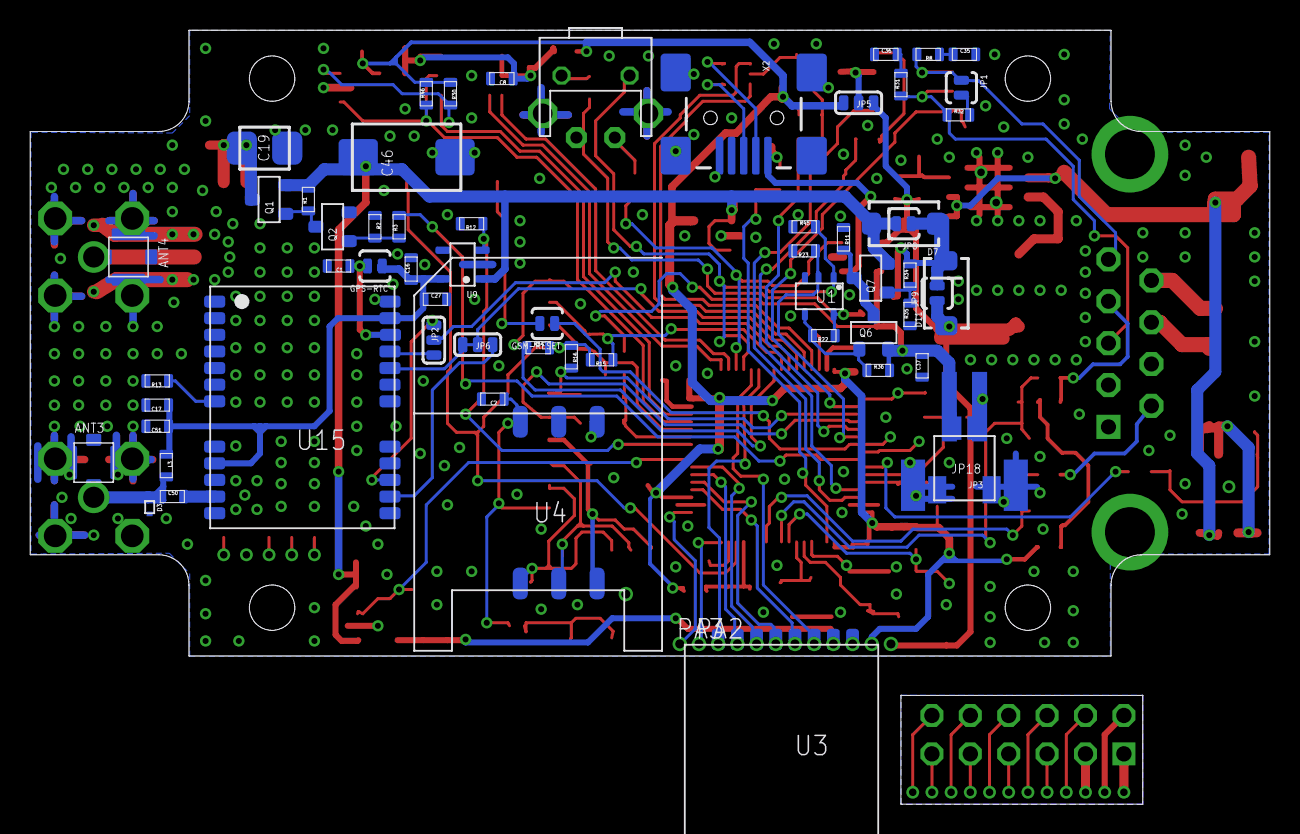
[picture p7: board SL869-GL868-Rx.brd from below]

Board: 2 copper layers, 82.0 x 41.4 mm, 196 parts (62 on the bottom side), 121 nets.

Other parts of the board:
U$1: G403

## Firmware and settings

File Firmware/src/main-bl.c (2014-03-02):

#include <string.h>

#include "hardware.h"
#include "main.h"
#include "debug.h"
#include "utility.h"
#include "fw_update.h"

#ifndef BL_VERSION

	#include "FreeRTOS.h"
	#include "task.h"
	#include "semphr.h"
	#include "gps.h"
	#include "gsm.h"
	#include "acc.h"
	#include "can.h"
	#include "gpsOne.h"
	#include "nmea/tok.h"
	#include "usb.h"

	#define LED_TASK_STACK_SIZE	(configMINIMAL_STACK_SIZE)
	#define ACC_TASK_STACK_SIZE	(configMINIMAL_STACK_SIZE)
	#define GPS_TASK_STACK_SIZE	(configMINIMAL_STACK_SIZE)
	#define CAN_TASK_STACK_SIZE	(configMINIMAL_STACK_SIZE)
	#define GSM_TASK_STACK_SIZE	(config_STACK_512)

	#define LED_TASK_PRIORITY	(tskIDLE_PRIORITY + 1)
	#define CAN_TASK_PRIORITY	(tskIDLE_PRIORITY + 2)
	#define GPS_TASK_PRIORITY	(tskIDLE_PRIORITY + 3)
	#define GSM_TASK_PRIORITY	(tskIDLE_PRIORITY + 4)

	xQueueHandle LedQueue;
	#if ( USE_USB )
		USB_OTG_CORE_HANDLE USB_OTG_dev;
	#endif
	void vLedTask(void * pvArg);
#endif

uint8_t HardwareInit(void);
void HardwareDeInit(void);

#if   defined( STM32F101RC )
	#warning "STM32F101RC"
#elif defined( STM32F205RE )
	#warning "STM32F205RE"
#elif defined( STM32F405RG )
	#warning "STM32F405RG"
#else
	#error "CPU not define"
#endif

uint8_t GlobalStatus;
volatile uint16_t VBATSum;
volatile uint16_t VBATCount;
volatile uint16_t VBATValue;

typedef void (*pFunction)(void);
pFunction Jump_To_Application;
uint32_t JumpAddress;

/*******************************************************************************
* Function Name	:	delay_ms
* Description	:	Delay in milliseconds with software loop
* Input			:	delay in ms
*******************************************************************************/
void delay_ms(uint16_t delay)
{
	volatile uint32_t count;
	volatile uint32_t cpu_delay = (SystemCoreClock / 1000UL) * 11988UL / 72000UL;
	while(delay != 0)
	{
		--delay;
		for(count = cpu_delay; count != 0; count--)
			__NOP();
	}
}

/*******************************************************************************
* Function Name	:	WaitForVDC
* Description	:	Wait for VDC
*******************************************************************************/

void WaitForVDC(void)
{
	while(1)
	{
		ShowFatalErrorOnly(ERROR_LOWEST_POWER);
		delay_ms(10000);
		if (VDC_CONNECT())
			SystemRestart();
	}
}

/*******************************************************************************
* Function Name	:	main
* Description	:	Main program
*******************************************************************************/
int main(void) __attribute__((noreturn));
int main(void)
{
	GlobalStatus	= 0;
	VBATSum			= 0;
	VBATCount		= 0;
	VBATValue		= 0;

	switch(HardwareInit())
	{
		case 1:	// Very low power, only deep sleep
			WaitForVDC();
			break;
		case 2:	// Low power, only send SMS and sleep
			GlobalStatus |= VBAT_LOW;
			break;
	}

#ifndef BL_VERSION

	#if (USE_FW_UPDATE)
		#warning USE_FW_UPDATE
		FwUpdateInit();
	#endif

	LedQueue = xQueueCreate(5, sizeof(u16));
	if (
			xTaskCreate ( vLedTask, NULL, LED_TASK_STACK_SIZE, NULL, LED_TASK_PRIORITY, NULL ) == pdPASS
		&&	xTaskCreate ( vGsmTask, NULL, GSM_TASK_STACK_SIZE, NULL, GSM_TASK_PRIORITY, NULL ) == pdPASS
		&&	xTaskCreate ( vGpsTask, NULL, GPS_TASK_STACK_SIZE, NULL, GPS_TASK_PRIORITY, NULL ) == pdPASS
	#if (USE_CAN_SUPPORT)
		&&	xTaskCreate ( vCanTask, NULL, CAN_TASK_STACK_SIZE, NULL, CAN_TASK_PRIORITY, NULL ) == pdPASS
	#endif
		)
		vTaskStartScheduler();	// Start the scheduler

	// Task create fail, display error and restart
	ShowFatalError(ERROR_TASK_FAILED);

#else	// BL_VERSION

	if ((!FwCheckCopy() || FwCopy()) && FwCheckWork())
	{
		HardwareDeInit();
		SystemInit();

		FLASH_Lock();
		RCC_APB2PeriphResetCmd(0xffffffff, ENABLE);
		RCC_APB1PeriphResetCmd(0xffffffff, ENABLE);
		RCC_APB2PeriphResetCmd(0xffffffff, DISABLE);
		RCC_APB1PeriphResetCmd(0xffffffff, DISABLE);

		JumpAddress = *(volatile uint32_t*) (FW_WORK_START + 4);
		Jump_To_Application = (pFunction) JumpAddress;
		/* Initialize user application's Stack Pointer */
		__set_MSP(*(volatile uint32_t*) FW_WORK_START);
		Jump_To_Application();
	}
	DebugPutLineln("Bad flash");
	ShowFatalError(ERROR_FLASH_ERASE);

#endif	// BL_VERSION
}

/*******************************************************************************
* Function Name	:	SystemRestart
* Description	:	Make MCU restart
*******************************************************************************/
void SystemRestart(void)
{
	__disable_irq();
	delay_ms(500);
	NVIC_SystemReset();
	while(1);
}

#ifndef BL_VERSION

/*******************************************************************************
* Function Name	:	vApplicationIdleHook
* Description	:	User defined function from within the idle task
*******************************************************************************/
void vApplicationIdleHook(void)
{
}

/*******************************************************************************
* Function Name	:	vApplicationIdleHook
* Description	:	User defined function from within the idle task
*******************************************************************************/
static uint8_t KeyState = 0;
static uint8_t KeyNumber;
static uint16_t KeyTimer;

void vApplicationTickHook(void)
{
	static uint8_t key_debounce;

	if (!KEY_PRESS())
	{
		if (KeyState != 0)
		{
			LED_OFF();
			if (KeyState == 3)
			{
				if (KeyNumber == 5)
					SystemRestart();

				ShowErrorFromISR(0x81);
				/*
				if (KeyNumber > 3)
				{
					KeyStage = 0;
					ShowErrorFromISR(0x81);
				}
				else
				{
					switch(KeyStage)
					{
					case 0:
						KeyNumber1 = KeyNumber;
						ShowErrorFromISR(0x82);
						break;
					case 1:
						KeyNumber2 = KeyNumber;
						ShowErrorFromISR(0x83);
						KeyStage = 0xFF;
						break;
					}
					++KeyStage;
				}
				*/
			}
			KeyState = 0;
		}
		return;
	}

	switch(KeyState)
	{
	case 0:
		key_debounce = 10;
		++KeyState;
		break;
	case 1:
		--key_debounce;
		if (key_debounce == 0)
		{
			LED_ON();
			KeyTimer = 2000;
			++KeyState;
		}
		break;
	case 2:
		--KeyTimer;
		if (KeyTimer == 0)
		{
			LED_OFF();
			KeyTimer = 1000;
			KeyNumber = 0;
			++KeyState;
		}
		break;
	case 3:
		--KeyTimer;
		if (KeyTimer == 0)
		{
			LED_ON();
			++KeyState;
			KeyTimer = 500;
		}
		break;
	case 4:
		--KeyTimer;
		if (KeyTimer == 0)
		{
			LED_OFF();
			KeyTimer = 1000;
			KeyState = 3;
			++KeyNumber;
		}
		break;
	}
}

/*******************************************************************************
* Function Name	:	vApplicationMallocFailedHook
* Description	:	Allocate memory fail
*******************************************************************************/
void vApplicationMallocFailedHook( void )
{
	DebugPutLineln("vApplicationMallocFailedHook");
	while(DebugFlush());
	ShowFatalError(ERROR_NO_TASK_MEMORY);
}

#endif
/*******************************************************************************
* Function Name	:	Exception_Handler
* Description	:	Unknown exception handler
*******************************************************************************/
void Exception_Handler(void)
{
	ShowFatalError(ERROR_UNKNOWN_EXCEPTION);
}

/*******************************************************************************
* Function Name	:	Exception_Handler
* Description	:	Unknownn interrupt handler
*******************************************************************************/
void Default_Handler(void)
{
	ShowFatalError(ERROR_UNKNOWN_INTERRUPT);
}

/*******************************************************************************
* Function Name	:	ShowFatalError
* Description	:	Show fatal errors and make a SystemReset
* Input			:	error code
*******************************************************************************/
void ShowFatalErrorOnly(u16 errorCode)
{
	uint8_t count;
	__disable_irq();
	count = errorCode >> 8;
	if (count != 0)
	{
		delay_ms(1000);
		while(count-- != 0)
		{
			LED_ON();
			delay_ms(30);
			LED_OFF();
			delay_ms(500);
		}
		delay_ms(500);
	}
	count = errorCode & 0xFF;
	if (count != 0)
	{
		delay_ms(500);
		while(count-- != 0)
		{
			LED_ON();
			delay_ms(30);
			LED_OFF();
			delay_ms(500);
		}
		delay_ms(1000);
	}
}

/*******************************************************************************
* Function Name	:	ShowFatalError
* Description	:	Add error to queue
* Input			:	error code
*******************************************************************************/
void ShowFatalError(uint16_t errorCode)
{
	ShowFatalErrorOnly(errorCode);
	SystemRestart();
}

#ifndef BL_VERSION

/*******************************************************************************
* Function Name	:	ShowErrorFromISR
* Description	:	Add error to queue
* Input			:	error code
*******************************************************************************/
void ShowErrorFromISR(u16 errorCode)
{
	portBASE_TYPE ledTaskSwitchNeed;
	if (LedQueue != NULL)
		xQueueSendFromISR(LedQueue, &errorCode, &ledTaskSwitchNeed);
}

/*******************************************************************************
* Function Name	:	ShowError
* Description	:	Add error to queue
* Input			:	error code
*******************************************************************************/
void ShowError(u16 errorCode)
{
	if (LedQueue != NULL)
		xQueueSend(LedQueue, &errorCode, 5000);
}

/*******************************************************************************
* Function Name	:	vLEDTask
* Description	:	LED Task
*******************************************************************************/
void SetLedWithoutKey(uint8_t state)
{
	if (KeyState == 0)
	{
		if (state)	LED_ON();
		else		LED_OFF();
	}
}

/*******************************************************************************
* Function Name	:	vLEDTask
* Description	:	LED Task
*******************************************************************************/
void vLedTask(void * pvArg)
{
	u16 errorCode;
	u8 count;

	LedQueue = xQueueCreate(5, sizeof(u16));
	if (LedQueue == NULL)
		ShowFatalError(ERROR_TASK_FAILED);

	while(1)
	{
		if (xQueueReceive(LedQueue, &errorCode, 500 ) == pdPASS)
		{
			count = errorCode >> 8;
			if (count != 0)
			{
				vTaskDelay(1000);
				while(count-- != 0)
				{
					SetLedWithoutKey(SET);
					vTaskDelay(50);
					SetLedWithoutKey(RESET);
					vTaskDelay(500);
				}
			}
			count = errorCode & 0xFF;
			if (count != 0)
			{
				if (count & 0x80)
				{
					vTaskDelay(300);
					count &= 0x7F;
					while(count-- != 0)
					{
						SetLedWithoutKey(SET);
						vTaskDelay(50);
						SetLedWithoutKey(RESET);
						vTaskDelay(300);
					}
					vTaskDelay(300);
				}
				else if (count == 1)
				{
					SetLedWithoutKey(SET);
					vTaskDelay(50);
					SetLedWithoutKey(RESET);
				}
				else
				{
					vTaskDelay(500);
					while(count-- != 0)
					{
						SetLedWithoutKey(SET);
						vTaskDelay(50);
						SetLedWithoutKey(RESET);
						vTaskDelay(500);
					}
					vTaskDelay(1000);
				}
			}
		}
		else
		{
#if (USE_FW_UPDATE)
			FwUpdateCheck();	// Process FW download
#endif
		}
		
#if ( USE_USB )
		if (USB_CONNECT())
		{
			if (!VCP_Initialize())
				USBD_Init ( &USB_OTG_dev,
							USB_OTG_FS_CORE_ID,
							(USBD_DEVICE *) &USR_desc,
							(USBD_Class_cb_TypeDef *) &USBD_CDC_cb,
							(USBD_Usr_cb_TypeDef *) &USR_cb
							);
		}
		else
		{
			if (VCP_Initialize())
			{
				USBD_USR_DeInit(&USB_OTG_dev);
			}
		}
#endif
	}
}

#endif

/*******************************************************************************
* Function Name	:	HardwareInit
* Description	:	Initialize hardware
*******************************************************************************/
void HardwareDeInit(void)
{
}

/*******************************************************************************
* Function Name	:	HardwareInit
* Description	:	Initialize hardware
*******************************************************************************/
uint8_t HardwareInit(void)
{
	NVIC_InitTypeDef nvi;
	ADC_InitTypeDef acdi;

#if defined( STM32F2XX ) || defined( STM32F4XX )
	ADC_CommonInitTypeDef ADC_CommonInitStructure;
#endif
#if (USE_SERIAL_DEBUG)
	USART_InitTypeDef USART_InitStructure;
#endif

	/* Configure HCLK clock as SysTick clock source. */
	SysTick_CLKSourceConfig( SysTick_CLKSource_HCLK );

	NVIC_PriorityGroupConfig(NVIC_PriorityGroup_1);
	nvi.NVIC_IRQChannelCmd = ENABLE;

#if defined( STM32F2XX ) || defined( STM32F4XX )
	// Enable CRC clock
	RCC_AHB1PeriphClockCmd(RCC_AHB1Periph_CRC, ENABLE);
	// Set all pins as analog input
	RCC_AHB1PeriphClockCmd (
		RCC_AHB1Periph_GPIOA |
		RCC_AHB1Periph_GPIOB |
		RCC_AHB1Periph_GPIOC |
		RCC_AHB1Periph_GPIOD,
		ENABLE);
	GPIOA->MODER	= 0x28000000;	// PA14/PA13 as SWD
	GPIOA->OTYPER	= 0;
	GPIOA->OSPEEDR	= 0;
	GPIOA->PUPDR	= 0x24000000;	// PA14 pull-up, PA13 pull-down

	GPIOB->MODER = 0; GPIOB->OTYPER = 0; GPIOB->OSPEEDR = 0; GPIOB->PUPDR = 0;
	GPIOC->MODER = 0; GPIOC->OTYPER = 0; GPIOC->OSPEEDR = 0; GPIOC->PUPDR = 0;
	GPIOD->MODER = 0; GPIOD->OTYPER = 0; GPIOD->OSPEEDR = 0; GPIOD->PUPDR = 0;
#endif

#if defined( STM32F10X_HD ) || defined( STM32F10X_MD )
	// Enable CRC clock
	RCC_AHBPeriphClockCmd(RCC_AHBPeriph_CRC, ENABLE);
	// Set all pins as analog input
	RCC_APB2PeriphClockCmd (
		RCC_APB2Periph_GPIOA |
		RCC_APB2Periph_GPIOB |
		RCC_APB2Periph_GPIOC |
		RCC_APB2Periph_GPIOD |
		RCC_APB2Periph_AFIO,
		ENABLE);
	// Enable SWD/SWC pins PA13, PA14
	// All other to analog in
	GPIOA->CRL = 0; GPIOA->CRH = 0x08800000;
	GPIOB->CRL = 0; GPIOB->CRH = 0;
	GPIOC->CRL = 0; GPIOC->CRH = 0;
	GPIOD->CRL = 0; GPIOD->CRH = 0;

	// Disable JTAG
	GPIO_PinRemapConfig(GPIO_Remap_SWJ_JTAGDisable, ENABLE);
#endif

	CPU_PWR_INIT();
	LED_INIT();
	VDC_INIT();
	VBAT_SENS_INIT();
	KEY_INIT();

#if defined ( STM32F10X_MD ) || defined ( STM32F10X_HD )

	nvi.NVIC_IRQChannel = ADC1_2_IRQn;
	nvi.NVIC_IRQChannelPreemptionPriority = 0;
	nvi.NVIC_IRQChannelSubPriority = 0;
	NVIC_Init(&nvi);

	RCC_ADCCLKConfig(RCC_PCLK2_Div4);
	RCC_APB2PeriphClockCmd(RCC_APB2Periph_ADC1, ENABLE);

	acdi.ADC_Mode = ADC_Mode_Independent;
	acdi.ADC_ScanConvMode = ENABLE;
	acdi.ADC_ContinuousConvMode = DISABLE;
	acdi.ADC_ExternalTrigConv = ADC_ExternalTrigConv_None;
	acdi.ADC_DataAlign = ADC_DataAlign_Right;
	acdi.ADC_NbrOfChannel = 1;
	ADC_Init(ADC1, &acdi);

	ADC_RegularChannelConfig(ADC1, ADC_Channel_9, 1, ADC_SampleTime_55Cycles5);
	ADC_Cmd(ADC1, ENABLE);

	ADC_ResetCalibration(ADC1);
	while(ADC_GetResetCalibrationStatus(ADC1));

	ADC_StartCalibration(ADC1);
	while(ADC_GetCalibrationStatus(ADC1));

	if (VDC_NOT_CONNECT())
	{
		ADC_ITConfig(ADC1, ADC_IT_EOC, ENABLE);
		// Need measure VBAT level and stop if low
		ADC_SoftwareStartConvCmd(ADC1, ENABLE);
		while ((GlobalStatus & VBAT_READY) == 0);
		GlobalStatus |= VBAT_STOPPED;
		if (VBATValue <= VBAT_ONLY_OFF)
		{
			ADC_ITConfig(ADC1, ADC_IT_EOC, DISABLE);
			ADC_Cmd(ADC1, DISABLE);
			RCC_APB2PeriphClockCmd(RCC_APB2Periph_ADC1, DISABLE);
			return 1;	// Very low battery level, stop immediatly
		}
		if (VBATValue <= VBAT_ONLY_OFF)
		{
			ADC_ITConfig(ADC1, ADC_IT_EOC, DISABLE);
			ADC_Cmd(ADC1, DISABLE);
			RCC_APB2PeriphClockCmd(RCC_APB2Periph_ADC1, DISABLE);
			return 2;	// Low battery level, send SMS and stop
		}
		ADC_ITConfig(ADC1, ADC_IT_EOC, DISABLE);
	}
#endif

#if defined ( STM32F2XX) || defined ( STM32F4XX )

	nvi->NVIC_IRQChannel = ADC_IRQn;
	nvi->NVIC_IRQChannelPreemptionPriority = 0;
	nvi->NVIC_IRQChannelSubPriority = 0;
	NVIC_Init(nvi);

	RCC_APB2PeriphClockCmd(RCC_APB2Periph_ADC1, ENABLE);

	ADC_CommonInitStructure.ADC_Mode = ADC_Mode_Independent;
	ADC_CommonInitStructure.ADC_Prescaler = ADC_Prescaler_Div2;
	ADC_CommonInitStructure.ADC_DMAAccessMode = ADC_DMAAccessMode_Disabled;
	ADC_CommonInitStructure.ADC_TwoSamplingDelay = ADC_TwoSamplingDelay_5Cycles;
	ADC_CommonInit(&ADC_CommonInitStructure);

	acdi.ADC_Resolution = ADC_Resolution_12b;
	acdi.ADC_ScanConvMode = DISABLE;
	acdi.ADC_ContinuousConvMode = ENABLE;
	acdi.ADC_ExternalTrigConvEdge = ADC_ExternalTrigConvEdge_None;
	acdi.ADC_DataAlign = ADC_DataAlign_Right;
	acdi.ADC_NbrOfConversion = 1;
	ADC_Init(ADC1, &acdi);

	ADC_RegularChannelConfig(ADC1, VBAT_CHANNEL, 1, ADC_SampleTime_15Cycles);
	ADC_Cmd(ADC1, ENABLE);

	if (VDC_NOT_CONNECT())
	{
		ADC_ITConfig(ADC1, ADC_IT_EOC, ENABLE);
		// Need measure VBAT level and stop if low
		ADC_SoftwareStartConv(ADC1);
		while ((GlobalStatus & VBAT_READY) == 0);
		GlobalStatus |= VBAT_STOPPED;
		if (VBATValue <= VBAT_ONLY_OFF)
		{
			ADC_ITConfig(ADC1, ADC_IT_EOC, DISABLE);
			ADC_Cmd(ADC1, DISABLE);
			RCC_APB2PeriphClockCmd(RCC_APB2Periph_ADC1, DISABLE);
			return 1;	// Very low battery level, stop immediatly
		}
		if (VBATValue <= VBAT_ONLY_OFF)
		{
			ADC_ITConfig(ADC1, ADC_IT_EOC, DISABLE);
			ADC_Cmd(ADC1, DISABLE);
			RCC_APB2PeriphClockCmd(RCC_APB2Periph_ADC1, DISABLE);
			return 2;	// Low battery level, send SMS and stop
		}
		ADC_ITConfig(ADC1, ADC_IT_EOC, DISABLE);
	}
#endif

	USB_DISC_INIT();
	USB_P_INIT();

#if (USE_SERIAL_DEBUG)
	nvi.NVIC_IRQChannel = DEBUG_USART_IRQn;
	nvi.NVIC_IRQChannelPreemptionPriority = 0;
	nvi.NVIC_IRQChannelSubPriority = 1;
	NVIC_Init(&nvi);

	DEBUG_INIT();

	USART_StructInit(&USART_InitStructure);
	USART_InitStructure.USART_BaudRate = 115200;
	USART_Init(DEBUG_USART, &USART_InitStructure);
	USART_Cmd(DEBUG_USART, ENABLE);

	DebugInit();
#endif

	DebugPutLineln("\nInitialization");

	SD_INIT();
	ACC_INIT();

	SENS_D1_INIT();
	SENS_A1_INIT();

	RELAY_INIT();

	GPS_INIT();
	GSM_INIT();

#if (USE_CAN_SUPPORT)
	CAN_INIT();
#endif

#ifndef BL_VERSION
#ifdef GPS_USART_IRQn
	nvi->NVIC_IRQChannel = GPS_USART_IRQn;
	nvi->NVIC_IRQChannelPreemptionPriority = 1;
	nvi->NVIC_IRQChannelSubPriority = 2;
	NVIC_Init(nvi);
#endif

#ifdef GSM_USART_IRQn
	nvi->NVIC_IRQChannel = GSM_USART_IRQn;
	nvi->NVIC_IRQChannelPreemptionPriority = 1;
	nvi->NVIC_IRQChannelSubPriority = 1;
	NVIC_Init(nvi);
#endif

#if (USE_CAN_SUPPORT)
#ifdef CAN_RX0_IRQn
	nvi->NVIC_IRQChannel = CAN_RX0_IRQn;
	nvi->NVIC_IRQChannelPreemptionPriority = 1;
	nvi->NVIC_IRQChannelSubPriority = 0;
	NVIC_Init(nvi);
#endif

#ifdef CAN_RX1_IRQn
	nvi->NVIC_IRQChannel = CAN_RX0_IRQn;
	nvi->NVIC_IRQChannelPreemptionPriority = 1;
	nvi->NVIC_IRQChannelSubPriority = 0;
	NVIC_Init(nvi);
#endif

#ifdef CAN_TX_IRQn
	nvi->NVIC_IRQChannel = CAN_TX_IRQn;
	nvi->NVIC_IRQChannelPreemptionPriority = 1;
	nvi->NVIC_IRQChannelSubPriority = 0;
	NVIC_Init(nvi);
#endif

#ifdef CAN_SCE_IRQn
	nvi->NVIC_IRQChannel = CAN_SCE_IRQn;
	nvi->NVIC_IRQChannelPreemptionPriority = 1;
	nvi->NVIC_IRQChannelSubPriority = 0;
	NVIC_Init(nvi);
#endif	//	CAN_SCE_IRQn

#endif	// USE_CAN_SUPPORT

#endif	// BL_VERSION

	return 0;
}

void ADC_IRQHandler(void)
{
	++VBATCount;
	VBATSum += ADC_GetConversionValue(ADC1);
	if (VBATCount >= 10)
	{
		if ((GlobalStatus & VBAT_READY) == 0)
		{
			VBATValue = VBATSum / VBATCount;
			GlobalStatus |= VBAT_READY;
		}
		VBATSum = 0;
		VBATCount = 0;
	}
	if ((GlobalStatus & VBAT_STOPPED) == 0)
	{
#if defined ( STM32F10X_HD ) || defined ( STM32F10X_MD )
		ADC_SoftwareStartConvCmd(ADC1, ENABLE);
#endif
#if defined ( STM32F2XX ) || defined ( STM32F4XX )
		ADC_SoftwareStartConv(ADC1);
#endif
	}
}

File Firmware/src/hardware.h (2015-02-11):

//*** <<< Use Configuration Wizard in Context Menu >>> ***
#ifndef __HARDWARE_H__
#define __HARDWARE_H__

#include "stm32fxxx.h"

#if		defined( STM32F2XX )	|| \
		defined( STM32F4XX )

	#define PinMode_AIn			(PinMode_Type)(GPIO_Mode_AIN)
	#define PinMode_In			(PinMode_Type)(GPIO_Mode_IN  | (GPIO_PuPd_NOPULL << 2))
	#define PinMode_In_PD		(PinMode_Type)(GPIO_Mode_IN  | (GPIO_PuPd_DOWN   << 2))
	#define PinMode_In_PU		(PinMode_Type)(GPIO_Mode_IN  | (GPIO_PuPd_UP     << 2))
	#define PinMode_Out_OD		(PinMode_Type)(GPIO_Mode_OUT | (GPIO_OType_OD << 6) | (GPIO_Speed_50MHz << 4))
	#define PinMode_Out_OD_2	(PinMode_Type)(GPIO_Mode_OUT | (GPIO_OType_OD << 6) | (GPIO_Speed_2MHz  << 4))
	#define PinMode_Out_PP		(PinMode_Type)(GPIO_Mode_OUT | (GPIO_OType_PP << 6) | (GPIO_Speed_50MHz << 4))
	#define PinMode_Out_PP_2	(PinMode_Type)(GPIO_Mode_OUT | (GPIO_OType_PP << 6) | (GPIO_Speed_2MHz  << 4))
	#define PinMode_AF_OD		(PinMode_Type)(GPIO_Mode_AF  | (GPIO_OType_OD << 6) | (GPIO_Speed_50MHz << 4))
	#define PinMode_AF_PP		(PinMode_Type)(GPIO_Mode_AF  | (GPIO_OType_PP << 6) | (GPIO_Speed_50MHz << 4))
	#define PinMode_AF_PP_100	(PinMode_Type)(GPIO_Mode_AF  | (GPIO_OType_PP << 6) | (GPIO_Speed_100MHz << 4))
	#define PinMode_AF_PP_PU	(PinMode_Type)(GPIO_Mode_AF  | (GPIO_OType_PP << 6) | (GPIO_PuPd_UP << 2) | (GPIO_Speed_50MHz  << 4))

#elif	defined( STM32F10X_HD )	|| \
		defined( STM32F10X_MD )	|| \
		defined( STM32F10X_MD_VL )

	#define PinMode_AIn			(PinMode_Type)(GPIO_Mode_AIN)
	#define PinMode_In			(PinMode_Type)(GPIO_Mode_IN_FLOATING)
	#define PinMode_In_PD		(PinMode_Type)(GPIO_Mode_IPD)
	#define PinMode_In_PU		(PinMode_Type)(GPIO_Mode_IPU)

	#define PinMode_Out_OD		(PinMode_Type)(GPIO_Mode_Out_OD | GPIO_Speed_50MHz)
	#define PinMode_Out_OD_2	(PinMode_Type)(GPIO_Mode_Out_OD | GPIO_Speed_2MHz)
	#define PinMode_Out_OD_10	(PinMode_Type)(GPIO_Mode_Out_OD | GPIO_Speed_10MHz)
	#define PinMode_Out_OD_50	(PinMode_Type)(GPIO_Mode_Out_OD | GPIO_Speed_50MHz)

	#define PinMode_Out_PP		(PinMode_Type)(GPIO_Mode_Out_PP | GPIO_Speed_50MHz)
	#define PinMode_Out_PP_2	(PinMode_Type)(GPIO_Mode_Out_PP | GPIO_Speed_2MHz)
	#define PinMode_Out_PP_10	(PinMode_Type)(GPIO_Mode_Out_PP | GPIO_Speed_10MHz)
	#define PinMode_Out_PP_50	(PinMode_Type)(GPIO_Mode_Out_PP | GPIO_Speed_50MHz)

	#define PinMode_AF_OD		(PinMode_Type)(GPIO_Mode_AF_OD  | GPIO_Speed_50MHz)
	#define PinMode_AF_PP		(PinMode_Type)(GPIO_Mode_AF_PP  | GPIO_Speed_50MHz)

#endif

typedef unsigned char PinMode_Type;
void	pinMode		(uint8_t pin, PinMode_Type mode);
void	pinLow		(uint8_t pin);
void	pinHigh		(uint8_t pin);
void	pinToggle	(uint8_t pin);
void	pinRemap	(uint8_t pin, uint8_t GPIO_AF);

void Led1_On(void);
void Led2_On(void);
void Leds_Off(void);
void Led_On(void);
void Led_Off(void);

#define ERROR_LOWEST_POWER			0x02

#define ERROR_GPS_TASK_NOT_ADD		0x12
#define ERROR_GPS_NO_DATA			0x13
#define ERROR_GPS_TASK_FAIL			0x14
#define ERROR_GPS_INIT_FAIL			0x15

#define ERROR_GSM_TCP_DISABLE		0x21
#define ERROR_GSM_TCP_NOT_OPEN		0x22
#define ERROR_GSM_SIM_NOT_READY		0x23
#define ERROR_GSM_NOT_REGISTER		0x24
#define ERROR_GSM_OTHER				0x25
#define ERROR_GSM_NOT_READY			0x26
#define ERROR_GSM_TASK_FAIL			0x27
#define ERROR_GSM_NO_SIM			0x28
#define ERROR_GSM_REG_DENIED		0x29

#define ERROR_CAN_TRANSMITE			0x31
#define ERROR_CAN_TASK_FAIL			0x32

#define ERROR_UNKNOWN_EXCEPTION		0x51
#define ERROR_UNKNOWN_INTERRUPT		0x52
#define ERROR_NO_TASK_MEMORY		0x53
#define ERROR_TASK_FAILED			0x54
#define ERROR_FLASH_ERASE			0x55
#define ERROR_MCU_HARD				0x56
#define ERROR_STACK_LOW				0x57

//	<h>		Communication
//	<s0>	APN Name
//			<i> GPRS APN name
//	<s1>	Username
//			<i> GPRS user name
//	<s2>	Password
//			<i> GPRS password
//	<s3>	Host Address
//			<i> IP address of host
//	<s4>	Port
//			<i> Host port
//	<o>		Protocol
//			<0x00=> TCP
//			<0x01=> HTTP
//			<i> Communication protocol
//	<s5>	FW Update Address
//			<i> IP address of FW update host
//	<s6>	Port
//			<i> FW update host port
//	</h>
#define DEF_GRPS_APN_NAME	"apn name"
#define DEF_GPRS_USERNAME	"username"
#define DEF_GPRS_PASSWORD	"password"
#define DEF_HOST_ADDR		"server_name_or_ip"
#define DEF_HOST_PORT		"server_port"
#define DEF_PROTOCOL		0x00
#define DEF_FOTA_ADDR		"update_server_name_ip"
#define DEF_FOTA_PORT		"update_server_port"

// Service center phones (use ones for init sms)
#define SMS_CENTER_1		"\"+00000000000\""
#define SMS_CENTER_2		"\"+00000000000\""

//	<e> Debug via Serial port
//	</e>
#define USE_SERIAL_DEBUG	1
//	<e> Debug via USB port
//	</e>
#define USE_USB_DEBUG		0

#if ( USE_SERIAL_DEBUG || USE_USB_DEBUG )
	#define USE_DEBUG		1
#else
	#define USE_DEBUG		0
#endif

//	<e> GPS Enable
//		<e1>	Use Kalman Filter
//		</e1>
//		<e2>	Use Average Filter
//		</e2>
//	</e>
#define USE_NMEA			1
#define USE_KALMAN			1
#define USE_AVERAGE			1

//	<e> CAN Support Enable
//	</e>
#define USE_CAN_SUPPORT		0
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

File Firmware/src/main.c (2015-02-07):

#include <string.h>
#include <stdint.h>

#include "hardware.h"
#include "main.h"
#include "debug.h"
#include "utility.h"
#include "fw_update.h"

#ifndef BL_VERSION

	#include "FreeRTOS.h"
	#include "task.h"
	#include "semphr.h"
	#include "gps.h"
	#include "gsm.h"
	#include "acc.h"
	#include "can.h"
	#include "gpsOne.h"
	#include "nmea/tok.h"
	#include "usb.h"

	#if ( USE_USB )
		USB_OTG_CORE_HANDLE USB_OTG_dev;
	#endif

	#if (USE_AVERAGE == 1)
		#warning AVERAGE FILTER
	#endif
	#if (USE_KALMAN == 1)
		#warning KALMAN FILTER
	#endif

#endif

#if   defined( STM32F101RC )
	#warning STM32F101RC
#elif defined( STM32F100CB )
	#warning STM32F100CB
#elif defined( STM32F205RE )
	#warning STM32F205RE
#elif defined( STM32F405RG )
	#warning STM32F405RG
#else
	#error "CPU not define"
#endif

const char VERSION[] = ",vers="VERSION_INFO;

uint8_t HardwareInit(void);

volatile uint16_t GlobalStatus;

#if defined ( VBAT_SENS_PIN )
	volatile uint16_t VBATSum;
	volatile uint16_t VBATCount;
	volatile uint16_t VBATValue;
#endif

typedef void (*pFunction)(void);

/*******************************************************************************
 * Function Name	:	main
 * Description	:	Main program
 *******************************************************************************/
int main(void) __attribute__((noreturn));
int main(void)
{
	RCC_ClearFlag();
	SystemCoreClockUpdate();

	DBGMCU_Config(DBGMCU_SLEEP | DBGMCU_STOP | DBGMCU_STANDBY, ENABLE);

	GlobalStatus	= 0;
	
#if defined ( VDC_NOT_CONNECT )
	VBATSum			= 0;
	VBATCount		= 0;
	VBATValue		= 0;

	switch (HardwareInit())
	{
		case 1:	// Very low power, only deep sleep
			WaitForVDC();
			break;
		case 2:	// Low power, only send SMS and sleep
			GlobalStatus |= VBAT_LOW;
			break;
	}
#else
	HardwareInit();
#endif

#ifndef BL_VERSION

	DEBUG("\nFW "VERSION_INFO"\n");

	#define GPS_TASK_STACK	(( unsigned short ) ( 680 / 4))
	#define GSM_TASK_STACK	(( unsigned short ) ( 740 / 4))

	if (xTaskCreate ( vGpsTask, "GPS", GPS_TASK_STACK, NULL, (tskIDLE_PRIORITY + 1), NULL ) == pdPASS
	&&	xTaskCreate ( vGsmTask, "GSM", GSM_TASK_STACK, NULL, (tskIDLE_PRIORITY + 2), NULL ) == pdPASS
	#if (USE_CAN_SUPPORT)
	&&	xTaskCreate ( vCanTask, NULL, CAN_TASK_STACK, NULL, (tskIDLE_PRIORITY + 3), NULL ) == pdPASS
	#endif
		)
		vTaskStartScheduler();			// Start the scheduler
	ShowFatalError(ERROR_TASK_FAILED);	// Task create fail, display error and restart

#else	// BL_VERSION

	DEBUG("\nBL "VERSION_INFO);

	FwCopyNew();

	if (FwCheckImage(FW_WORK_START))
	{
		DEBUG(" run\n");
		FLASH_Lock();
		/* Initialize user application's Stack Pointer */
		__set_MSP(*(volatile uint32_t*) FW_WORK_START);
		((pFunction)(*(uint32_t*)(FW_WORK_START + 4)))();
	}

	DEBUG(" no app\n");
	ShowFatalError(ERROR_FLASH_ERASE);

#endif	// BL_VERSION
}


#ifndef BL_VERSION

	#if defined ( STM32F10X_HD ) || defined ( STM32F10X_MD ) || defined ( STM32F10X_MD_VL )
		void Disable_WWDG(void)
		{
			WWDG_DeInit();
		}

		void Reset_WWDG(void)
		{
			uint8_t cnt = WWDG->CR & 0x7F;
			if (cnt < 80)
				WWDG_SetCounter(127);
		}

		void Enable_WWDG(void)
		{
			RCC_APB1PeriphClockCmd(RCC_APB1Periph_WWDG, ENABLE);
			DBGMCU_Config(DBGMCU_WWDG_STOP, ENABLE);
			WWDG_SetPrescaler(WWDG_Prescaler_8);
			WWDG_SetWindowValue(80);
			WWDG_Enable(127);
		}
	#else
		void Disable_WWDG(void)
		{ }
		void Reset_WWDG(void)
		{ }
		void Enable_WWDG(void)
		{ }
	#endif

	/*******************************************************************************
	* Function Name	:	vApplicationIdleHook
	* Description	:	User defined function from within the idle task
	*******************************************************************************/
	void vApplicationIdleHook(void)
	{
	#if ( USE_USB == 1)
		#warning USE_USB
		if (USB_CONNECT())
		{
			if (!VCP_Initialize())
				USBD_Init ( &USB_OTG_dev,
							USB_OTG_FS_CORE_ID,
							(USBD_DEVICE *) &USR_desc,
							(USBD_Class_cb_TypeDef *) &USBD_CDC_cb,
							(USBD_Usr_cb_TypeDef *) &USR_cb
							);
		}
		else
		{
			if (VCP_Initialize())
			{
				USBD_USR_DeInit(&USB_OTG_dev);
			}
		}
	#endif
	}

	/*******************************************************************************
	* Function Name	:	vApplicationMallocFailedHook
	* Description	:	Allocate memory fail
	*******************************************************************************/
	void vApplicationMallocFailedHook( void )
	{
		DEBUG("*** vApplicationMallocFailedHook\n");
		while(DebugFlush())
		{ }
		ShowFatalError(ERROR_NO_TASK_MEMORY);
	}

	/*******************************************************************************
	* Function Name	:	vApplicationIdleHook
	* Description	:	User defined function from within the idle task
	*******************************************************************************/
	extern uint32_t __initial_sp;
	void vApplicationStackOverflowHook( xTaskHandle *pxTask, signed char *pcTaskName )
	{
		__set_MSP(__initial_sp);

		DebugPutLine("\nStack overflow:");
		DebugPutLine((const char *)pcTaskName);
		DebugPutLine("\n");
		ShowFatalError(ERROR_STACK_LOW);
	}

#ifdef DISPLAY_STACK
	extern size_t xFreeBytesRemaining;
	void DisplayStackHigh(const char *msg)
	{
		static char local_buffer[20];
		unsigned portBASE_TYPE stackHigh = uxTaskGetStackHighWaterMark(NULL);
		DEBUG(msg);
		itoa(local_buffer, stackHigh, 0);
		DEBUG(local_buffer);
		DEBUG(" (");
		itoa(local_buffer, xFreeBytesRemaining, 0);
		DEBUG(local_buffer);
		DEBUG_LINE(")");
	}
#endif
#endif

/*******************************************************************************
* Function Name	:	WaitForVDC
* Description	:	Wait for VDC
*******************************************************************************/

void WaitForVDC(void)
{
#if defined ( VDC_CONNECT )
	while(1)
	{
		ShowFatalErrorOnly(ERROR_LOWEST_POWER);
		DWT_Delay_ms(10000);
		if (VDC_CONNECT())
			SystemRestart();
	}
#else
	DWT_Delay_ms(10000);
	SystemRestart();
#endif
}

/*******************************************************************************
* Function Name	:	SystemRestart
* Description	:	Make MCU restart
*******************************************************************************/
void SystemRestart(void)
{
	__disable_irq();

#ifndef BL_VERSION
	#if defined ( STM32F10X_HD ) || defined ( STM32F10X_MD )
		WWDG_DeInit();
	#endif
#endif

#if	defined ( STM32F10X_MD )	|| \
	defined ( STM32F10X_HD )	|| \
	defined ( STM32F10X_MD_VL )

	RCC_APB2PeriphResetCmd(0xFFFFFFFF, ENABLE);
	RCC_APB1PeriphResetCmd(0xFFFFFFFF, ENABLE);
	RCC_APB2PeriphResetCmd(0xFFFFFFFF, DISABLE);
	RCC_APB1PeriphResetCmd(0xFFFFFFFF, DISABLE);
#else
	#error "CPU not define"
#endif

	DWT_Delay_ms(500);
	NVIC_SystemReset();
	while(1);
}
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

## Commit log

2014-03-02 Commit firmware for STM32F10xCx (48 pins) and STM32F10xRx (64 pins)
    [SL869-GL868-Cx.brd, SL869-GL868-Cx.sch, SL869-GL868-Rx.brd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]
2014-03-24 Add remark for R9 and R13 values
    [SL869-GL868-Rx.brd, SL869-GL868-Rx.sch]
2014-04-25 Add links to OSH Park
    [SL869-GL868-Cx.brd, SL869-GL868-Rx.brd]
2014-04-25 Cosmetic changes
    [SL869-GL868-Cx.brd]
2014-04-25 Fix error with OSH Park DRU file
    [SL869-GL868-Cx.brd, SL869-GL868-Rx.brd]
2014-04-26 Add to Readme.md about Cx version w/o STM32 MCU
2014-06-07 Fix schematic/layout
    [SL869-GL868-Rx.brd, SL869-GL868-Rx.sch]
2014-12-25 Fix error with LED on PB3/PB4 with Cx version
    [SL869-GL868-Cx.brd, SL869-GL868-Cx.sch]
2015-02-07 Fox for RX (64 pin CPU) version
2015-02-11 Fix CTS pin initialization
    [hardware.h]
